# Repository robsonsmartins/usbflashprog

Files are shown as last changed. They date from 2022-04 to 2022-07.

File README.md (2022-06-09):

# usbflashprogUSB Flash/EPROM Programmer
A memory device programmer (Flash/EPROM/E2PROM) board and software, connected to PC by USB port.

[][tag-url] [][commit-url] [][forks-url] [][stars-url] [][issues-url] [][license-url] [][site-url]

[][build-firmware-url]
[][build-software-url]
[][test-software-url]
[][test-firmware-url]
[][codeql-url]

## Contents

* [About the Project](#about-the-project)
* [Current Status](#current-status)
* [Releases](#releases)
* [Documentation](#documentation)
* [Hardware Design](#hardware-design)
* [Firmware Project](#firmware-project)
* [Software Project](#software-project)
* [Contributing](#contributing)
* [License](#license)
* [Contact](#contact)
* [Reference](#reference)

## About The Project

The purpose of this board is to allow the programming, reading and verification of writable/rewritable memory devices, such as EPROM, EEPROM, Flash, SRAM, NVRAM – those with parallel bus as well as serial ones (I2C, SPI, Microwire, LPC).

In a future release, programming of some microcontroller families (eg. Microchip PIC, or 8051) may also be supported, via firmware and software upgrade.

## Current Status

The current status of this project is:










## Releases

The releases of this project are here: [Releases of the USB Flash/EPROM Programmer](https://github.com/robsonsmartins/usbflashprog/releases).

## Documentation

The most up-to-date project documentation can be accessed here: [Documentation of the USB Flash/EPROM Programmer](https://robsonsmartins.github.io/usbflashprog/).

## Hardware Design

The most up-to-date hardware design can be accessed here: [Hardware design of the USB Flash/EPROM Programmer](https://github.com/robsonsmartins/usbflashprog/blob/main/hardware/).

## Firmware Project

The most up-to-date firmware project can be accessed here: [Firmware Project of the USB Flash/EPROM Programmer](https://github.com/robsonsmartins/usbflashprog/blob/main/firmware/).

Instructions on how to build the firmware are described in following document: [Firmware Build Instructions](https://github.com/robsonsmartins/usbflashprog/blob/main/firmware/BUILD.md).

## Software Project

The most up-to-date software project can be accessed here: [Software Project of the USB Flash/EPROM Programmer](https://github.com/robsonsmartins/usbflashprog/blob/main/software/).

Instructions on how to build the software are described in following document: [Software Build Instructions](https://github.com/robsonsmartins/usbflashprog/blob/main/software/BUILD.md).

## Contributing

Please read [CONTRIBUTING](https://github.com/robsonsmartins/usbflashprog/blob/main/CONTRIBUTING.md) for more information.

## License

Distributed under the [Creative Commons Attribution-NonCommercial-ShareAlike 4.0 International License][cc-by-nc-sa]. 

See [LICENSE](https://github.com/robsonsmartins/usbflashprog/blob/main/LICENSE) file for more information.

The same "Terms and Conditions" and "Privacy Policy" of the [Robson Martins Home Page](https://www.robsonmartins.com) apply here:

- [Terms and Conditions](https://www.robsonmartins.com/content/policy/terms.php)
- [Privacy Policy](https://www.robsonmartins.com/content/policy/privacy.php)

## Contact

[][contact-site-url] [][contact-linkedin-url]

## Reference
* [EzoFlash+](http://www.ezoflash.com/) - Parallel Port EPROM/Flash Programmer.
* [MPSP](https://mpsp.robsonmartins.com) - Microchip&copy; PIC Serial Port Programmer.
* [PK2C](https://pk2c.robsonmartins.com) - Microchip&copy; PIC Kit 2 Clone Programmer.

---

This work is licensed under a [Creative Commons Attribution-NonCommercial-ShareAlike 4.0 International License][cc-by-nc-sa].

[][cc-by-nc-sa]

[cc-by-nc-sa]: http://creativecommons.org/licenses/by-nc-sa/4.0/
[cc-by-nc-sa-image]: https://licensebuttons.net/l/by-nc-sa/4.0/88x31.png

[tag-shield]: https://img.shields.io/github/v/tag/robsonsmartins/usbflashprog?style=plastic
[tag-url]: https://github.com/robsonsmartins/usbflashprog/tags
[commit-shield]: https://img.shields.io/github/last-commit/robsonsmartins/usbflashprog?style=plastic
[commit-url]: https://github.com/robsonsmartins/usbflashprog/graphs/commit-activity
[forks-shield]: https://img.shields.io/github/forks/robsonsmartins/usbflashprog?style=plastic
[forks-url]: https://github.com/robsonsmartins/usbflashprog/network/members
[stars-shield]: https://img.shields.io/github/stars/robsonsmartins/usbflashprog?style=plastic
[stars-url]: https://github.com/robsonsmartins/usbflashprog/stargazers
[issues-shield]: https://img.shields.io/github/issues/robsonsmartins/usbflashprog?style=plastic
[issues-url]: https://github.com/robsonsmartins/usbflashprog/issues
[license-shield]: https://img.shields.io/badge/License-CC%20BY--NC--SA%204.0-lightgrey.svg?style=plastic
[license-url]: https://github.com/robsonsmartins/usbflashprog/blob/master/LICENSE
[site-shield]: https://img.shields.io/badge/project%20site-usbflashprog-orange?style=plastic
[site-url]: https://usbflashprog.robsonmartins.com

[build-firmware-shield]: https://github.com/robsonsmartins/usbflashprog/actions/workflows/firmware.yml/badge.svg?style=plastic
[build-firmware-url]: https://github.com/robsonsmartins/usbflashprog/actions/workflows/firmware.yml
[build-software-shield]: https://github.com/robsonsmartins/usbflashprog/actions/workflows/software.yml/badge.svg?style=plastic
[build-software-url]: https://github.com/robsonsmartins/usbflashprog/actions/workflows/software.yml
[test-firmware-shield]: https://github.com/robsonsmartins/usbflashprog/actions/workflows/test-firmware.yml/badge.svg?style=plastic
[test-firmware-url]: https://github.com/robsonsmartins/usbflashprog/actions/workflows/test-firmware.yml
[test-software-shield]: https://github.com/robsonsmartins/usbflashprog/actions/workflows/test-software.yml/badge.svg?style=plastic
[test-software-url]: https://github.com/robsonsmartins/usbflashprog/actions/workflows/test-software.yml
[codeql-shield]: https://github.com/robsonsmartins/usbflashprog/actions/workflows/codeql-analysis.yml/badge.svg?style=plastic
[codeql-url]:https://github.com/robsonsmartins/usbflashprog/actions/workflows/codeql-analysis.yml

[contact-site-shield]: https://img.shields.io/badge/Home%20Page-robsonmartins.com-green?style=plastic
[contact-site-url]: https://www.robsonmartins.com
[contact-linkedin-shield]: https://img.shields.io/badge/LinkedIn-robsonmartins-blue?style=plastic
[contact-linkedin-url]: https://www.linkedin.com/in/robsonmartins/

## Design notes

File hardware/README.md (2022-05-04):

# usbflashprogUSB Flash/EPROM Programmer

A memory device programmer (Flash/EPROM/E2PROM) board and software, connected to PC by USB port.

## Hardware Design

### Schematic Diagram

The most up-to-date schematic diagram can be accessed here: [Schematic diagram of the USB Flash/EPROM Programmer](https://robsonsmartins.github.io/usbflashprog/hardware/usbflashprog_sch.pdf).

### Bill of Materials (BOM)

The most up-to-date BOM can be accessed here: [Bill of Materials of the USB Flash/EPROM Programmer](https://robsonsmartins.github.io/usbflashprog/hardware/usbflashprog_bom.pdf).

## Software versions

The following CAD software (opensource and multiplatform) was used to draw the schematic diagram and PCB:

- [Kicad](https://www.kicad.org), version 6.0.4.

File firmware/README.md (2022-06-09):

# usbflashprogUSB Flash/EPROM Programmer

A memory device programmer (Flash/EPROM/E2PROM) board and software, connected to PC by USB port.

## Firmware Project

### Build Instructions

Instructions on how to build the project are described in following document: [Build Instructions](BUILD.md)

### Raspberry Pi Pico Platform

- [Raspberry Pi Documentation](https://www.raspberrypi.com/documentation/microcontrollers/raspberry-pi-pico.html)
- [Raspberry Pi Pico Datasheet](https://datasheets.raspberrypi.com/pico/pico-datasheet.pdf)
- [Getting started with Raspberry Pi Pico (C/C++)](https://datasheets.raspberrypi.com/pico/getting-started-with-pico.pdf)
- [Raspberry Pi Pico C/C++ SDK](https://www.raspberrypi.com/documentation/microcontrollers/c_sdk.html)

### Code Style Guide

- [Google C++ Style Guide](https://google.github.io/styleguide/cppguide.html)

## Software versions

The following software was used to develop the firmware:

- [Ubuntu GNU/Linux](https://releases.ubuntu.com/jammy/), version 22.04 LTS.
- [Visual Studio Code](https://code.visualstudio.com/), version 1.66.2.
- [OpenOCD](https://github.com/raspberrypi/openocd), version 0.11.0-g610f137.
- [Pico SDK](https://github.com/raspberrypi/pico-sdk), version 1.3.0.
- [ARM GCC](https://packages.ubuntu.com/jammy/gcc-arm-none-eabi), version 15:10.3-2021.07-4.
- [GCC](https://packages.ubuntu.com/jammy/gcc), version 4:11.2.0-1ubuntu1.
- [CMake](https://packages.ubuntu.com/jammy/cmake), version 3.22.1-1ubuntu1.
- [Google Test](https://packages.ubuntu.com/jammy/googletest), version 1.11.0-3.
- [Doxygen](https://packages.ubuntu.com/jammy/doxygen), version 1.9.1-2ubuntu2.

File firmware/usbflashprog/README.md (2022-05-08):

## USB EPROM/Flash Programmer

A memory device programmer (Flash/EPROM/E2PROM) board and software, connected to PC by USB port.

### About The Project

The purpose of this board is to allow the programming, reading and verification of writable/rewritable memory devices, such as EPROM, EEPROM, Flash, SRAM, NVRAM – those with parallel bus as well as serial ones (I2C, SPI, Microwire, LPC).

In a future release, programming of some microcontroller families (eg. Microchip PIC, or 8051) may also be supported, via firmware and software upgrade.

### License

This work is licensed under a [Creative Commons Attribution-NonCommercial-ShareAlike 4.0 International License](http://creativecommons.org/licenses/by-nc-sa/4.0/).



### Repository

- [Firmware Project](https://github.com/robsonsmartins/usbflashprog/tree/main/firmware)

### Firmware Documentation

The most up-to-date firmware documentation can be accessed here: [Firmware Documentation of the USB Flash/EPROM Programmer](https://robsonsmartins.github.io/usbflashprog/firmware/html/index.html).

### Code Coverage Report

The code coverage report from unit tests can be accessed here: [Code Coverage Report of the USB Flash/EPROM Programmer](https://robsonsmartins.github.io/usbflashprog/firmware/lcov/index.html).

### Raspberry Pi Pico Platform

- [Raspberry Pi Documentation](https://www.raspberrypi.com/documentation/microcontrollers/raspberry-pi-pico.html)
- [Raspberry Pi Pico Datasheet](https://datasheets.raspberrypi.com/pico/pico-datasheet.pdf)
- [Getting started with Raspberry Pi Pico (C/C++)](https://datasheets.raspberrypi.com/pico/getting-started-with-pico.pdf)
- [Raspberry Pi Pico C/C++ SDK](https://www.raspberrypi.com/documentation/microcontrollers/c_sdk.html)

### Code Style Guide

- [Google C++ Style Guide](https://google.github.io/styleguide/cppguide.html)

### Software versions

The following software was used to develop the firmware:

- [Ubuntu GNU/Linux](https://releases.ubuntu.com/jammy/), version 22.04 LTS.
- [Visual Studio Code](https://code.visualstudio.com/), version 1.66.2.
- [OpenOCD](https://github.com/raspberrypi/openocd), version 0.11.0-g610f137.
- [Pico SDK](https://github.com/raspberrypi/pico-sdk), version 1.3.0.
- [ARM GCC](https://packages.ubuntu.com/jammy/gcc-arm-none-eabi), version 15:10.3-2021.07-4.
- [GCC](https://packages.ubuntu.com/jammy/gcc), version 4:11.2.0-1ubuntu1.
- [CMake](https://packages.ubuntu.com/jammy/cmake), version 3.22.1-1ubuntu1.
- [Google Test](https://packages.ubuntu.com/jammy/googletest), version 1.11.0-3.
- [LCov](https://packages.ubuntu.com/jammy/lcov), version 1.15-1.
- [Doxygen](https://packages.ubuntu.com/jammy/doxygen), version 1.9.1-2ubuntu2.

**author** [Robson Martins](https://www.robsonmartins.com)

**version** 0.1

**date** 2022

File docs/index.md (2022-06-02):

# usbflashprogUSB Flash/EPROM Programmer

A memory device programmer (Flash/EPROM/E2PROM) board and software, connected to PC by USB port.

## Project Site

[USB Flash/EPROM Programmer Project Site](https://usbflashprog.robsonmartins.com)

## Documentation

### Specifications

The most up-to-date project specifications can be accessed here: [Specifications of the USB Flash/EPROM Programmer](https://robsonsmartins.github.io/usbflashprog/specs.pdf).

### Firmware Documentation

The most up-to-date firmware documentation can be accessed here: [Firmware Documentation of the USB Flash/EPROM Programmer](https://robsonsmartins.github.io/usbflashprog/firmware/html/index.html).

### Software Documentation

The most up-to-date software documentation can be accessed here: [Software Documentation of the USB Flash/EPROM Programmer](https://robsonsmartins.github.io/usbflashprog/software/html/index.html).

### Hardware Documentation

#### Schematic Diagram

The most up-to-date schematic diagram can be accessed here: [Schematic diagram of the USB Flash/EPROM Programmer](https://robsonsmartins.github.io/usbflashprog/hardware/usbflashprog_sch.pdf).

#### Bill of Materials (BOM)

The most up-to-date BOM can be accessed here: [Bill of Materials of the USB Flash/EPROM Programmer](https://robsonsmartins.github.io/usbflashprog/hardware/usbflashprog_bom.pdf).

## Software versions

The following software (open source/freeware and multiplatform) were used to write the documentation:

- [LibreOffice](https://www.libreoffice.org/), version 7.3.2.2.
- [yEd Graph Editor](https://www.yworks.com/products/yed), version 3.22.
- [Doxygen](https://packages.ubuntu.com/jammy/doxygen), version 1.9.1-2ubuntu2.

---

This work is licensed under a [Creative Commons Attribution-NonCommercial-ShareAlike 4.0 International License][cc-by-nc-sa].

[][cc-by-nc-sa]

[cc-by-nc-sa]: http://creativecommons.org/licenses/by-nc-sa/4.0/
[cc-by-nc-sa-image]: https://licensebuttons.net/l/by-nc-sa/4.0/88x31.png

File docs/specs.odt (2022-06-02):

USB Flash / EPROM Programmer

https://usbflashprog.robsonmartins.com

Specifications

Version 0.1 - Revision F

Author: Robson Martins (https://www.robsonmartins.com)

History

Revision | Date | Changes
F | May. 30, 2022 | Added serial communication protocol (opcodes).
E | Apr. 23, 2022 | CPU changed to Raspberry Pi Pico. Updated diagrams. Removed PT_BR translation.
D | Feb. 02, 2011 | Added firmware project.
C | Dec. 27, 2010 | Added adapter connectors pin-out.
B | Mar. 03, 2010 | New Block Diagram.
A | Jan. 28, 2010 | Initial Version.

# Introduction

The purpose of this board is to allow the programming, reading and verification of writable/rewritable memory devices, such as EPROM, EEPROM, Flash, SRAM, NVRAM – those with parallel bus as well as serial ones (I2C, SPI, Microwire, LPC).

In a future release, programming of some microcontroller families (eg. Microchip PIC, or 8051) may also be supported, via firmware and software upgrade.

# Requirements

- Allow write, read, delete, get ID and information about supported chips.
- Support parallel and serial devices (no microcontrollers in initial version).
- Support SRAM, EPROM, E2PROM, Flash, NVRAM, Hub/LPC devices (parallel and serial, including Microwire, I2C, SPI).
- Provide two sources of programming voltage: VDD (low voltage) and VPP/VEE (high voltage for write/erase), in the range between 3.3 V and 6.8 V (VDD), and between 12V and 25V (VPP/VEE).
- Automatic control for VDD and VPP/VEE voltages, according to the chip to be programmed.
- Allow jumperless chip configuration (by software chip selection).
- Socket for adapters – for each package or family of supported chips (no ZIF socket on the programmer board).
- Algorithms for chip read/write operations must be loaded on the main board of the programmer through ‘scripts’, avoiding the use of processing by software running on the PC.
- Connection with PC via USB port, using a specific software for communication.
- Multi-platform software, compatible with Microsoft Windows® or GNU/Linux® operating systems, under 32 or 64 bits (if possible, Apple MacOSX® and FreeBSD versions can be available).
- Some compatibility with existing programmers adapters:
  - EzoFlash+ (http://www.ezoflash.com/).
  - MPSP (https://mpsp.robsonmartins.com).

# Hardware Platform

## Block Diagram

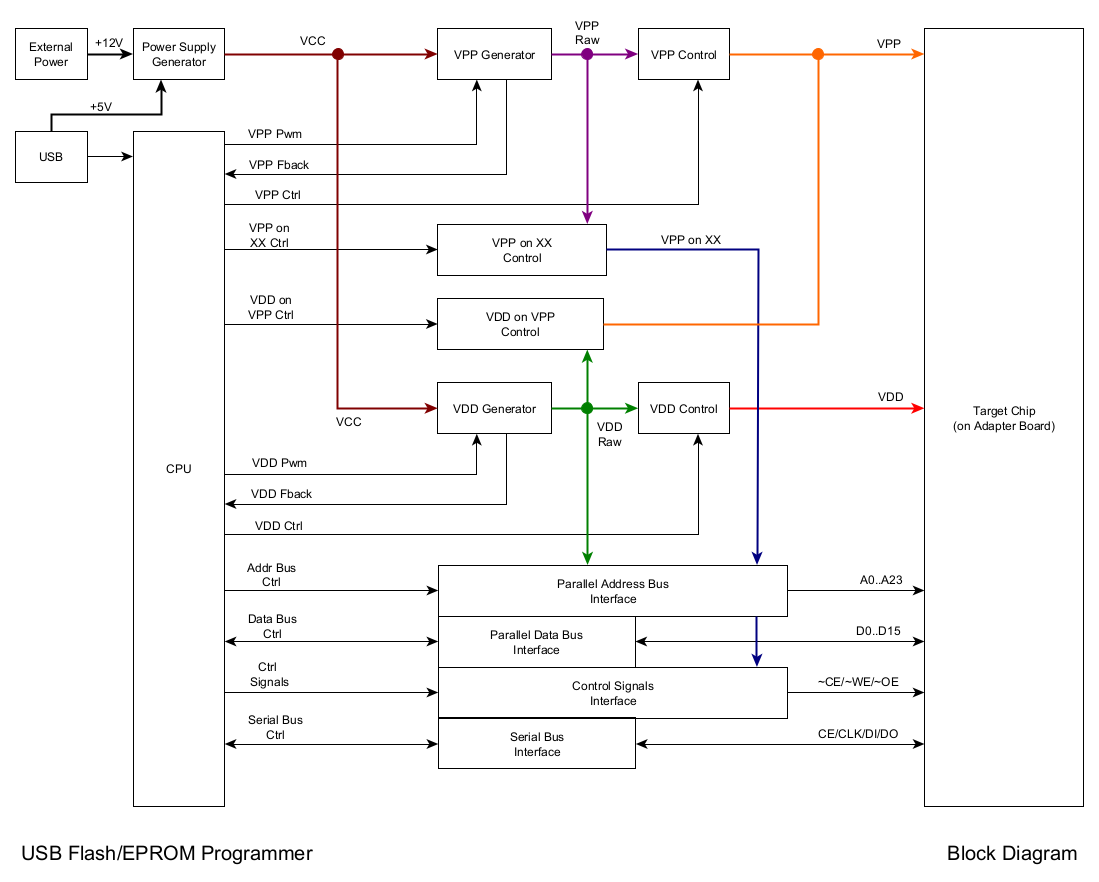
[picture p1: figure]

## Functional Description

### Main CPU

The CPU used in this programmer will be a Raspberry Pi Pico Module (with a RP2040 processor and USB support). This module has a dual core ARM Cortex-M0+ running at 133MHz, 256KB of SRAM and 2MB of storage, a USB port, required for communication between the programmer and the PC, plus one A/D converter with 3 inputs and 16 PWM channels (that can be used to generate the programming voltages). Moreover, there is a serial communication port (SPI / Microwire / I2C) that can be used for programming of serial devices, and GPIO pins to control parallel bus and signals.

### Power Supplies

To generate the programming voltages (VDD and VPP/VEE), the programmer must have two DC/DC converters, driven by the PWM outputs of the CPU and monitored through of the ADC inputs.

Both the CPU and the two DC/DC converters will be powered by voltage supplied by USB port (5V), and/or by external power supply connector.

The CPU can turn on or off the VDD / VPP / VEE outputs, or supply VDD voltage on VPP line (via the “VDD on VPP” signal).

### Programmer Busses

For handle parallel devices, the programmer must provide the following busses and signals to the target chip:

- Address Bus (A0..A23) – A addressing bus with 24 bits wide, allowing access up to 16777216 positions (16M).
- Data Bus (D0..D7 / D8..D15) – A data bus with 8 or 16 bits wide, allowing access for one byte (8 bits) or one word (16 bits), according to the memory width.
- Control Lines (~CE / ~WE / ~OE) – Chip Enable, Write Enable e Output Enable.
- Power and Programming Voltages (VDD / VPP / VEE) - Voltages used to power-up (VDD), program (VPP) or erase (VEE) the memory.

For handle serial devices, the programmer must provide the following signals to the target chip:

- Clock (CLK) – Clock line for synchronize the communication with the target memory.
- Data Input (DIN) – For read data from target memory.
- Data Output (DOUT) – For write data to target memory.
- Control Lines (~CE / ~WE / ~OE) – Chip Enable, Write Enable e Output Enable.
- Power and Programming Voltages (VDD / VPP / VEE) - Voltages used to power-up (VDD), program (VPP) or erase (VEE) the memory.

### Busses Interfaces

To connect the microcontroller busses to target chip, is necessary adapt the voltage levels of the CPU (5V) and the voltage levels of the target chip (3.3V <= VDD <= 6.8V), using an interface circuitry.

## Adapter Connector Pin-Out

### Parallel Adapter Connector

Female (Top Side)

1 | 3 | 5 | 7 | 9 | 11 | 13 | 15 | 17 | 19 | 21 | 23 | 25 | 27 | 29 | 31 | 33 | 35 | 37 | 39 | 41 | 43 | 45 | 47
2 | 4 | 6 | 8 | 10 | 12 | 14 | 16 | 18 | 20 | 22 | 24 | 26 | 28 | 30 | 32 | 34 | 36 | 38 | 40 | 42 | 44 | 46 | 48

Pin | Function | Description
1 | D0 | DATA BUS – BIT 0
2 | D1 | DATA BUS – BIT 1
3 | D2 | DATA BUS – BIT 2
4 | GND | GROUND
5 | D3 | DATA BUS – BIT 3
6 | D4 | DATA BUS – BIT 4
7 | D5 | DATA BUS – BIT 5
8 | D6 | DATA BUS – BIT 6
9 | D7 | DATA BUS – BIT 7
10 | CE | CHIP ENABLE
11 | A10 | ADDRESS BUS – BIT 10
12 | OE | OUTPUT ENABLE
13 | A11 | ADDRESS BUS – BIT 11
14 | A9 | ADDRESS BUS – BIT 9
15 | A8 | ADDRESS BUS – BIT 8
16 | A13 | ADDRESS BUS – BIT 13
17 | A14 | ADDRESS BUS – BIT 14
18 | A17 | ADDRESS BUS – BIT 17
19 | WE | WRITE ENABLE
20 | VDD | VDD VOLTAGE
21 | A18 | ADDRESS BUS – BIT 18
22 | A16 | ADDRESS BUS – BIT 16
23 | A15 | ADDRESS BUS – BIT 15
24 | A12 | ADDRESS BUS – BIT 12
25 | A7 | ADDRESS BUS – BIT 7
26 | A6 | ADDRESS BUS – BIT 6
27 | A5 | ADDRESS BUS – BIT 5
28 | A4 | ADDRESS BUS – BIT 4
29 | A3 | ADDRESS BUS – BIT 3
30 | A2 | ADDRESS BUS – BIT 2
31 | A1 | ADDRESS BUS – BIT 1
32 | A0 | ADDRESS BUS – BIT 0
33 | KEY | KEY TO AVOID CONNECTOR INVERSION
34 | VPP | VPP PROGRAMMING VOLTAGE
35 | A19 | ADDRESS BUS – BIT 19
36 | A20 | ADDRESS BUS – BIT 20
37 | A21 | ADDRESS BUS – BIT 21
38 | A22 | ADDRESS BUS – BIT 22
39 | A23 | ADDRESS BUS – BIT 23
40 | KEY | KEY TO AVOID CONNECTOR INVERSION
41 | D8 | DATA BUS – BIT 8
42 | D9 | DATA BUS – BIT 9
43 | D10 | DATA BUS – BIT 10
44 | D11 | DATA BUS – BIT 11
45 | D12 | DATA BUS – BIT 12
46 | D13 | DATA BUS – BIT 13
47 | D14 | DATA BUS – BIT 14
48 | D15 | DATA BUS – BIT 15

### Serial Adapter Connector

Female (Top Side)

1 | 3 | 5 | 7 | 9 | 11 | 13 | 15 | 17 | 19
2 | 4 | 6 | 8 | 10 | 12 | 14 | 16 | 18 | 20

Pin | Function | Description
1 | VPP13 | VPP PROGRAMMING VOLTAGE (13V)
2 | VPP13 | VPP PROGRAMMING VOLTAGE (13V)
3 | VDD5 | VDD VOLTAGE (5V)
4 | VDD5 | VDD VOLTAGE (5V)
5 | GND | GROUND
6 | GND | GROUND
7 | SCK | SERIAL CLOCK
8 | SCK | SERIAL CLOCK
9 | GND | GROUND
10 | GND | GROUND
11 | SDO | SERIAL DATA OUT (TO TARGET SDI)
12 | SDI | SERIAL DATA IN (FROM TARGET SDO)
13 | GND | GROUND
14 | GND | GROUND
15 | VCC | VCC SUPPLY (5V – ALWAYS ON)
16 | VCC | VCC SUPPLY (5V – ALWAYS ON)
17 | WE | CHIP SELECT (WE PROGRAMMER PIN)
18 | WE | CHIP SELECT (WE PROGRAMMER PIN)
19 | GND | GROUND
20 | KEY | KEY TO AVOID CONNECTOR INVERSION

# Firmware Project

## Block Diagram

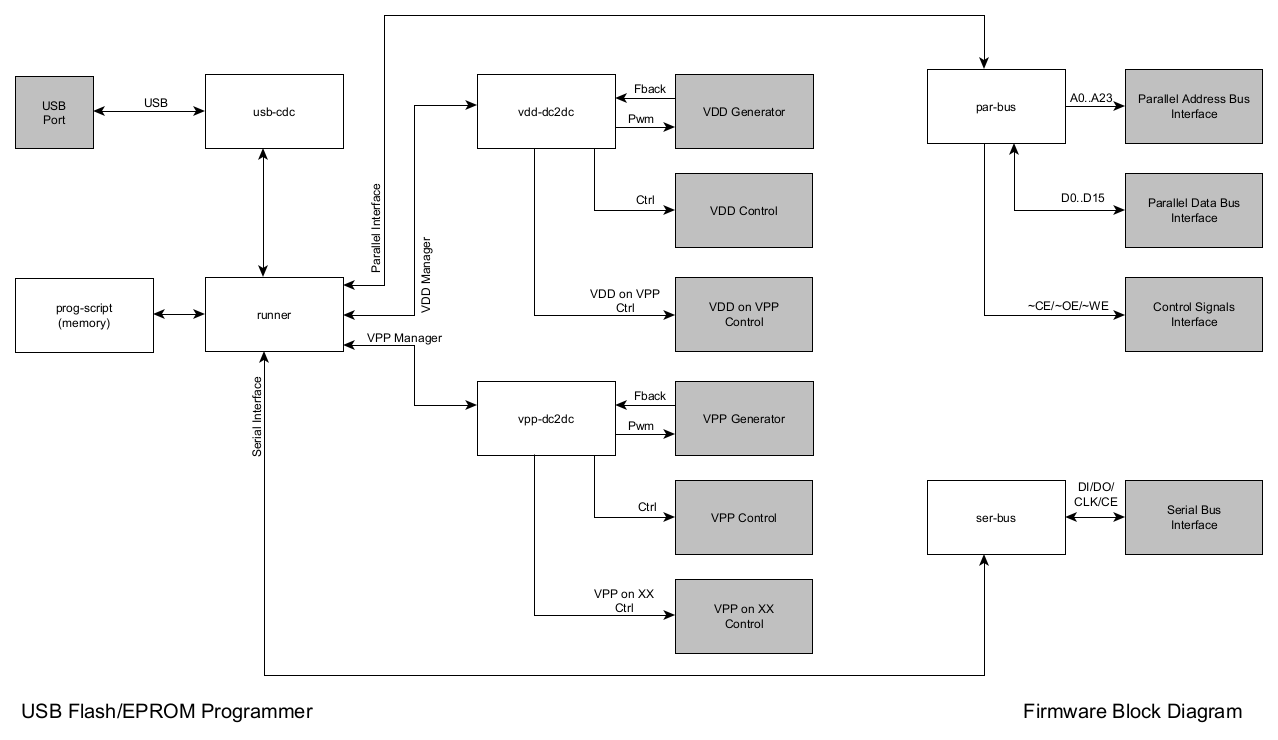
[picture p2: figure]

## Communication Protocol (Opcodes)

For communication between the programmer’s hardware and the PC, the following protocol must be used (via USB-CDC serial class).

### Response Codes

Op Code | Mnemonic | Description
0x00 | CMD RESPONSE NOK | Response NOK.
0x01 | CMD RESPONSE OK | Response OK.

### Command Codes

Op Code | Mnemonic | Parameters | Response | Description
0x00 | NOP | <none> | OK | No Operation.
0x01 | CMD VDD CTRL | STATE | OK NOK | Set VDD Ctrl Pin On or Off. Parameter STATE is one byte size. If STATE == 0x00, will be OFF; If STATE != 0x00, will be ON.
0x02 | CMD VDD SETV | VALUE | OK NOK | Set VDD Voltage. Parameter VALUE is two byte size. FIRST = Integer part of value SECOND = Fractional part of value
0x03 | CMD VDD GETV | <none> | OK + VALUE NOK | Get VDD Voltage. Response VALUE is two byte size. FIRST = Integer part of value SECOND = Fractional part of value
0x04 | CMD VDD GET% | <none> | OK + VALUE NOK | Get VDD PWM Duty Cycle (%). Response VALUE is two byte size. FIRST = Integer part of value SECOND = Fractional part of value
0x05 | CMD VDD GETCAL | <none> | OK + VALUE NOK | Get VDD Calibration Value. Response VALUE is two byte size. FIRST = Integer part of value SECOND = Fractional part of value
0x06 | CMD VDD INITCAL | <none> | OK NOK | Init VDD Calibration Process.
0x07 | CMD VDD SAVECAL | VALUE | OK NOK | Save VDD Calibration Value. Parameter VALUE is two byte size. FIRST = Integer part of value SECOND = Fractional part of value
0x08 | CMD VDD ON VPP | STATE | OK NOK | Set VDD On VPP Pin On or Off. Parameter STATE is one byte size. If STATE == 0x00, will be OFF; If STATE != 0x00, will be ON.
0x11 | CMD VPP CTRL | STATE | OK NOK | Set VPP Ctrl Pin On or Off. Parameter STATE is one byte size. If STATE == 0x00, will be OFF; If STATE != 0x00, will be ON.
0x12 | CMD VPP SETV | VALUE | OK NOK | Set VPP Voltage. Parameter VALUE is two byte size. FIRST = Integer part of value SECOND = Fractional part of value
0x13 | CMD VPP GETV | <none> | OK + VALUE NOK | Get VPP Voltage. Response VALUE is two byte size. FIRST = Integer part of value SECOND = Fractional part of value
0x14 | CMD VPP GET% | <none> | OK + VALUE NOK | Get VPP PWM Duty Cycle (%). Response VALUE is two byte size. FIRST = Integer part of value SECOND = Fractional part of value
0x15 | CMD VPP GETCAL | <none> | OK + VALUE NOK | Get VPP Calibration Value. Response VALUE is two byte size. FIRST = Integer part of value SECOND = Fractional part of value
0x16 | CMD VPP INITCAL | <none> | OK NOK | Init VPP Calibration Process.
0x17 | CMD VPP SAVECAL | VALUE | OK NOK | Save VPP Calibration Value. Parameter VALUE is two byte size. FIRST = Integer part of value SECOND = Fractional part of value
0x18 | CMD VPP ON A9 | STATE | OK NOK | Set VPP On A9 Pin On or Off. Parameter STATE is one byte size. If STATE == 0x00, will be OFF; If STATE != 0x00, will be ON.
0x19 | CMD VPP ON A18 | STATE | OK NOK | Set VPP On A18 Pin On or Off. Parameter STATE is one byte size. If STATE == 0x00, will be OFF; If STATE != 0x00, will be ON.
0x1A | CMD VPP ON CE | STATE | OK NOK | Set VPP On CE Pin On or Off. Parameter STATE is one byte size. If STATE == 0x00, will be OFF; If STATE != 0x00, will be ON.
0x1B | CMD VPP ON OE | STATE | OK NOK | Set VPP On OE Pin On or Off. Parameter STATE is one byte size. If STATE == 0x00, will be OFF; If STATE != 0x00, will be ON.
0x1C | CMD VPP ON WE | STATE | OK NOK | Set VPP On WE Pin On or Off. Parameter STATE is one byte size. If STATE == 0x00, will be OFF; If STATE != 0x00, will be ON.
0x21 | CMD BUS CE CTRL | STATE | OK NOK | Set CE Pin On or Off. Parameter STATE is one byte size. If STATE == 0x00, will be OFF; If STATE != 0x00, will be ON.
0x22 | CMD BUS OE CTRL | STATE | OK NOK | Set OE Pin On or Off. Parameter STATE is one byte size. If STATE == 0x00, will be OFF; If STATE != 0x00, will be ON.
0x23 | CMD BUS WE CTRL | STATE | OK NOK | Set WE Pin On or Off. Parameter STATE is one byte size. If STATE == 0x00, will be OFF; If STATE != 0x00, will be ON.
0x31 | CMD BUS AD CLR | <none> | OK NOK | Clear Address Bus Value (Set Address to 0x00).
0x32 | CMD BUS AD INC | <none> | OK NOK | Increment Address Bus Value.
0x33 | CMD BUS AD SET | VALUE | OK NOK | Set Address Bus Value. Parameter VALUE is three byte size. FIRST = HI SECOND = MID THIRD = LOW
0x34 | CMD BUS AD SETB | VALUE | OK NOK | Set Address Bus Value (BYTE). Parameter VALUE is one byte size. VALUE = LOW
0x35 | CMD BUS AD SETW | VALUE | OK NOK | Set Address Bus Value (WORD). Parameter VALUE is two byte size. FIRST = MID SECOND = LOW
0x41 | CMD BUS DT CLR | <none> | OK NOK | Clear Data Bus Value (Set Data to 0x00).
0x42 | CMD BUS DT SET | VALUE | OK NOK | Set Data Bus Value. Parameter VALUE is two byte size. FIRST = HI SECOND = LOW
0x43 | CMD BUS DT SETB | VALUE | OK NOK | Set Data Bus Value (BYTE). Parameter VALUE is one byte size. VALUE = LOW
0x44 | CMD BUS DT GET | <none> | OK + VALUE NOK | Get Data Bus Value. Response VALUE is two byte size. FIRST = HI SECOND = LOW
0x45 | CMD BUS DT GETB | <none> | OK + VALUE NOK | Get Data Bus Value (BYTE). Response VALUE is one byte size. VALUE = LOW
TODO | CMD SERIAL BUS | | | TODO: Serial Bus Commands.

Appendix A – Development Environment

To develop the programmer, should be used only open source and freeware software:

- Operating System:
  - GNU/Linux (https://distrowatch.com/)
- Documentation:
  - LibreOffice (https://www.libreoffice.org/)
  - yEd Graph Editor (https://www.yworks.com/products/yed)
- Hardware Development:
  - CAD:
    - Kicad (https://www.kicad.org)
- Firmware Development:
  - Raspberry Pi Pico Module:
    - Raspberry Pi Pico (https://www.raspberrypi.com/products/raspberry-pi-pico/)
- Software Development:
  - C/C++ Compiler:
    - GCC (https://gcc.gnu.org/)
  - GUI Framework:
    - Qt (https://www.qt.io)
  - IDE:
    - Qt Creator (https://www.qt.io/product/development-tools)
    - Microsoft Visual Studio Code (https://code.visualstudio.com/)
  - Code Documentation:
    - Doxygen (https://www.doxygen.org/)
  - Software Modeling:
    - Umbrello (https://umbrello.kde.org/)
- Version Control System:
  - Git (https://git-scm.com/)

USB Flash / EPROM Programmer 3

USB Flash / EPROM Programmer 5

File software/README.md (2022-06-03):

# usbflashprogUSB Flash/EPROM Programmer

A memory device programmer (Flash/EPROM/E2PROM) board and software, connected to PC by USB port.

## Software Project

### Build Instructions

Instructions on how to build the project are described in following document: [Build Instructions](BUILD.md)

### Code Style Guide

- [Google C++ Style Guide](https://google.github.io/styleguide/cppguide.html)

## Software versions

The following software was used to develop the software:

- [Ubuntu GNU/Linux](https://releases.ubuntu.com/jammy/), version 22.04 LTS.
- [Visual Studio Code](https://code.visualstudio.com/), version 1.66.2.
- [GCC](https://packages.ubuntu.com/jammy/gcc), version 4:11.2.0-1ubuntu1.
- [Qt](https://packages.ubuntu.com/jammy/qttools5-dev-tools), version 5.15.3-1.
- [Qt tools support for VSCode](https://marketplace.visualstudio.com/items?itemName=tonka3000.qtvsctools), version 0.11.0.
- [CMake](https://packages.ubuntu.com/jammy/cmake), version 3.22.1-1ubuntu1.
- [Google Test](https://packages.ubuntu.com/jammy/googletest), version 1.11.0-3.
- [Doxygen](https://packages.ubuntu.com/jammy/doxygen), version 1.9.1-2ubuntu2.

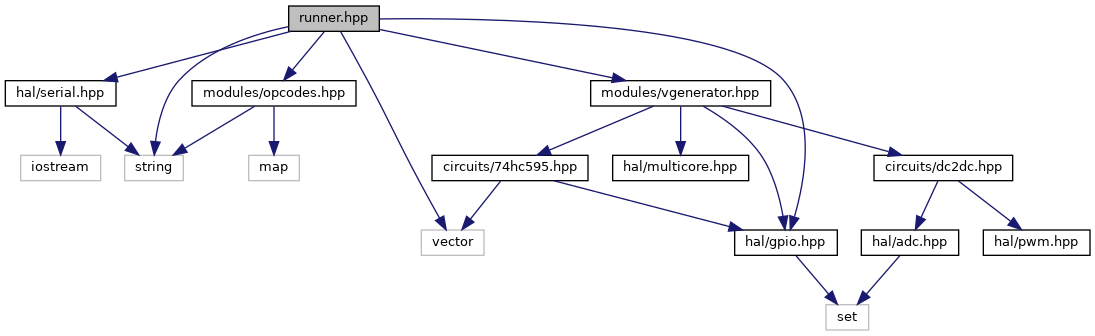
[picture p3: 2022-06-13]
docs/firmware/html/a00072.png

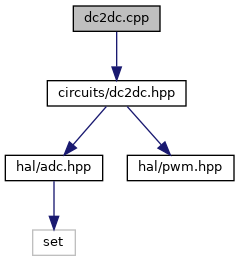
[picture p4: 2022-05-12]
docs/firmware/html/a00009.png

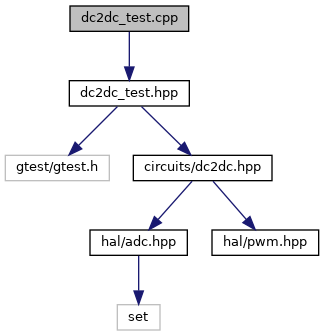
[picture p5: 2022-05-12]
docs/firmware/html/a00090.png

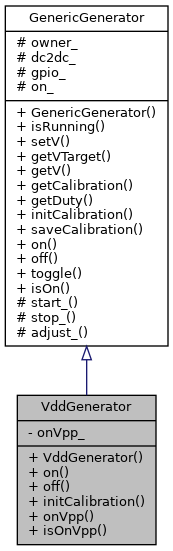
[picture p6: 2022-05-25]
docs/firmware/html/a01061.png

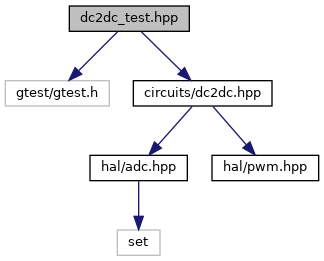
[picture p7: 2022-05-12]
docs/firmware/html/a00093.png

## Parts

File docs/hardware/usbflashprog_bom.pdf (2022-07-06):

## USB Flash / EPROM Programmer

## BOM (Bill of Materials)

Source: | usbflashprog.kicad_sch
Date: | 06/07/22 00:07
Tool: | Eeschema (6.0.4)
Generator: | bom_csv_grouped_by_value.py
Component Count: 123
Item | Qty | Reference(s) | Value
1 | 1 | C1 | 10uF x 25V
2 | 1 | C2 | 10uF x 16V
3 | 13 | C3, C5, C7, C9, C10, C11, C12, C13, C14, C15, C16, C17, C18 | 100nF
4 | 1 | C4 | 470uF x 16V
5 | 1 | C6 | 22uF x 16V
6 | 1 | C8 | 100uF x 50V
7 | 3 | D1, D2, D4 | 1N4001
8 | 1 | D3 | LED GREEN 3mm
9 | 3 | D5, D7, D11 | BAT46
10 | 1 | D6 | LED RED 3mm
11 | 2 | D8, D19 | 1N4733A (5V1)
12 | 8 | D9, D12, D13, D14, D15, D16, D17, D18 | 1N4148
13 | 1 | D10 | LED YELLOW 3mm
14 | 1 | D20 | 1N4743A (13V)
15 | 1 | J1 | Power Jack
16 | 1 | J2 | 48 pin socket
17 | 1 | J3 | 20 pin socket
18 | 1 | L1 | 100uH
19 | 1 | L2 | 300uH
20 | 6 | Q1, Q12, Q13, Q14, Q15, Q16 | BC547
21 | 4 | Q2, Q3, Q4, Q6 | BC327
22 | 1 | Q5 | TIP120
23 | 5 | Q7, Q8, Q9, Q10, Q11 | BC557
24 | 14 | R1, R5, R6, R7, R12, R13, R18, R25, R26, R33, R35, R37, R49, R50 | 2K2 x 1/8W
25 | 5 | R27, R28, R38, R39, R42 | 2K2 x 1W
26 | 3 | R2, R15, R40 | 100R x 1/8W
27 | 2 | R11, R51 | 100R x 1/2W
28 | 7 | R3, R8, R22, R43, R45, R47, R48 | 1K x 1/8W
29 | 10 | R4, R17, R19, R23, R24, R29, R30, R31, R44, R46 | 4K7 x 1/8W
30 | 5 | R9, R21, R34, R36, R41 | 470R x 1/8W
31 | 1 | R10 | 330R x 1/8W
32 | 2 | R14, R32 | 10K x 1/8W
33 | 1 | R16 | 220R x 1/8W
34 | 1 | R20 | 3K9 x 1/8W
35 | 1 | R52 | 560R x 1W
36 | 1 | U1 | LM7809
37 | 2 | U2, U8 | 74LS06N
38 | 1 | U3 | Raspberry Pi Pico
39 | 6 | U4, U5, U6, U7, U9, U10 | 74HC595
40 | 2 | U11, U12 | 74HC165

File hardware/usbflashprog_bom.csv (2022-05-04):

Source: | usbflashprog.kicad_sch
Date: | 27/04/2022 23:32:14
Tool: | Eeschema (6.0.4)
Generator: | bom_csv_grouped_by_value.py
Component Count: | 123
Individual Components:
Item | Qty | Reference(s) | Value | LibPart | Footprint | Datasheet
 |  | C1 | 10uF | Device:C_Polarized | Capacitor_THT:CP_Radial_D8.0mm_P3.50mm | ~
 |  | C2 | 10uF | Device:C_Polarized | Capacitor_THT:CP_Radial_D8.0mm_P3.50mm | ~
 |  | C3 | 100nF | Device:C | Capacitor_THT:C_Disc_D6.0mm_W2.5mm_P5.00mm | ~
 |  | C4 | 470uF | Device:C_Polarized | Capacitor_THT:CP_Radial_D10.0mm_P7.50mm | ~
 |  | C5 | 100nF | Device:C | Capacitor_THT:C_Disc_D6.0mm_W2.5mm_P5.00mm | ~
 |  | C6 | 22uF | Device:C_Polarized | Capacitor_THT:CP_Radial_D8.0mm_P3.50mm | ~
 |  | C7 | 100nF | Device:C | Capacitor_THT:C_Disc_D6.0mm_W2.5mm_P5.00mm | ~
 |  | C8 | 100uF | Device:C_Polarized | Capacitor_THT:C_Disc_D6.0mm_W2.5mm_P5.00mm | ~
 |  | C9 | 100nF | Device:C | Capacitor_THT:C_Disc_D6.0mm_W2.5mm_P5.00mm | ~
 |  | C10 | 100nF | Device:C | Capacitor_THT:C_Disc_D6.0mm_W2.5mm_P5.00mm | ~
 |  | C11 | 100nF | Device:C | Capacitor_THT:C_Disc_D6.0mm_W2.5mm_P5.00mm | ~
 |  | C12 | 100nF | Device:C | Capacitor_THT:C_Disc_D6.0mm_W2.5mm_P5.00mm | ~
 |  | C13 | 100nF | Device:C | Capacitor_THT:C_Disc_D6.0mm_W2.5mm_P5.00mm | ~
 |  | C14 | 100nF | Device:C | Capacitor_THT:C_Disc_D6.0mm_W2.5mm_P5.00mm | ~
 |  | C15 | 100nF | Device:C | Capacitor_THT:C_Disc_D6.0mm_W2.5mm_P5.00mm | ~
 |  | C16 | 100nF | Device:C | Capacitor_THT:C_Disc_D6.0mm_W2.5mm_P5.00mm | ~
 |  | C17 | 100nF | Device:C | Capacitor_THT:C_Disc_D6.0mm_W2.5mm_P5.00mm | ~
 |  | C18 | 100nF | Device:C | Capacitor_THT:C_Disc_D6.0mm_W2.5mm_P5.00mm | ~
 |  | D1 | 1N4001 | Diode:1N4001 | Diode_THT:D_DO-41_SOD81_P10.16mm_Horizontal | http://www.vishay.com/docs/88503/1n4001.pdf
 |  | D2 | 1N4001 | Diode:1N4001 | Diode_THT:D_DO-41_SOD81_P10.16mm_Horizontal | http://www.vishay.com/docs/88503/1n4001.pdf
 |  | D3 | GREEN | Device:LED | LED_THT:LED_D3.0mm | ~
 |  | D4 | 1N4001 | Diode:1N4001 | Diode_THT:D_DO-41_SOD81_P10.16mm_Horizontal | http://www.vishay.com/docs/88503/1n4001.pdf
 |  | D5 | BAT46 | Diode:BAT46 | Diode_THT:D_DO-35_SOD27_P7.62mm_Horizontal | http://www.vishay.com/docs/85662/bat46.pdf
 |  | D6 | RED | Device:LED | LED_THT:LED_D3.0mm | ~
 |  | D7 | BAT46 | Diode:BAT46 | Diode_THT:D_DO-35_SOD27_P7.62mm_Horizontal | http://www.vishay.com/docs/85662/bat46.pdf
 |  | D8 | 1N4733A | Diode:1N47xxA | Diode_THT:D_DO-41_SOD81_P10.16mm_Horizontal | https://www.vishay.com/docs/85816/1n4728a.pdf
 |  | D9 | 1N4148 | Diode:1N4148 | Diode_THT:D_DO-35_SOD27_P7.62mm_Horizontal | https://assets.nexperia.com/documents/data-sheet/1N4148_1N4448.pdf
 |  | D10 | YELLOW | Device:LED | LED_THT:LED_D3.0mm | ~
 |  | D11 | BAT46 | Diode:BAT46 | Diode_THT:D_DO-35_SOD27_P7.62mm_Horizontal | http://www.vishay.com/docs/85662/bat46.pdf
 |  | D12 | 1N4148 | Diode:1N4148 | Diode_THT:D_DO-35_SOD27_P7.62mm_Horizontal | https://assets.nexperia.com/documents/data-sheet/1N4148_1N4448.pdf
 |  | D13 | 1N4148 | Diode:1N4148 | Diode_THT:D_DO-35_SOD27_P7.62mm_Horizontal | https://assets.nexperia.com/documents/data-sheet/1N4148_1N4448.pdf
 |  | D14 | 1N4148 | Diode:1N4148 | Diode_THT:D_DO-35_SOD27_P7.62mm_Horizontal | https://assets.nexperia.com/documents/data-sheet/1N4148_1N4448.pdf
 |  | D15 | 1N4148 | Diode:1N4148 | Diode_THT:D_DO-35_SOD27_P7.62mm_Horizontal | https://assets.nexperia.com/documents/data-sheet/1N4148_1N4448.pdf
 |  | D16 | 1N4148 | Diode:1N4148 | Diode_THT:D_DO-35_SOD27_P7.62mm_Horizontal | https://assets.nexperia.com/documents/data-sheet/1N4148_1N4448.pdf
 |  | D17 | 1N4148 | Diode:1N4148 | Diode_THT:D_DO-35_SOD27_P7.62mm_Horizontal | https://assets.nexperia.com/documents/data-sheet/1N4148_1N4448.pdf
 |  | D18 | 1N4148 | Diode:1N4148 | Diode_THT:D_DO-35_SOD27_P7.62mm_Horizontal | https://assets.nexperia.com/documents/data-sheet/1N4148_1N4448.pdf
 |  | D19 | 1N4733A | Diode:1N47xxA | Diode_THT:D_DO-41_SOD81_P10.16mm_Horizontal | https://www.vishay.com/docs/85816/1n4728a.pdf
 |  | D20 | 1N4743A | Diode:1N47xxA | Diode_THT:D_DO-41_SOD81_P10.16mm_Horizontal | https://www.vishay.com/docs/85816/1n4728a.pdf
 |  | J1 | 12-18V | Connector:Barrel_Jack_Switch | Connector_BarrelJack:BarrelJack_Horizontal | ~
 |  | J2 | Parallel Adapter | Connector_Generic:Conn_02x24_Odd_Even | Connector_PinSocket_2.54mm:PinSocket_2x24_P2.54mm_Vertical | ~
 |  | J3 | Serial Adapter | Connector_Generic:Conn_02x10_Odd_Even | Connector_PinSocket_2.54mm:PinSocket_2x10_P2.54mm_Vertical | ~
 |  | L1 | 100uH | Device:L_Ferrite | Inductor_THT:L_Toroid_Vertical_L13.0mm_W6.5mm_P5.60mm | ~
 |  | L2 | 300uH | Device:L_Ferrite | Inductor_THT:L_Toroid_Vertical_L16.0mm_W8.0mm_P7.62mm | ~
 |  | Q1 | BC547 | Transistor_BJT:BC547 | Package_TO_SOT_THT:TO-92_Inline | https://www.onsemi.com/pub/Collateral/BC550-D.pdf
 |  | Q2 | BC327 | :BC327_1 | Package_TO_SOT_THT:TO-92_Inline | http://www.onsemi.com/pub_link/Collateral/BC327-D.PDF
 |  | Q3 | BC327 | :BC327_2 | Package_TO_SOT_THT:TO-92_Inline | http://www.onsemi.com/pub_link/Collateral/BC327-D.PDF
 |  | Q4 | BC327 | Transistor_BJT:BC327 | Package_TO_SOT_THT:TO-92_Inline | http://www.onsemi.com/pub_link/Collateral/BC327-D.PDF
 |  | Q5 | TIP120 | Transistor_BJT:TIP120 | Package_TO_SOT_THT:TO-220-3_Vertical | https://www.onsemi.com/pub/Collateral/TIP120-D.PDF
 |  | Q6 | BC327 | Transistor_BJT:BC327 | Package_TO_SOT_THT:TO-92_Inline | http://www.onsemi.com/pub_link/Collateral/BC327-D.PDF
 |  | Q7 | BC557 | :BC557_1 | Package_TO_SOT_THT:TO-92_Inline | https://www.onsemi.com/pub/Collateral/BC556BTA-D.pdf
 |  | Q8 | BC557 | Transistor_BJT:BC557 | Package_TO_SOT_THT:TO-92_Inline | https://www.onsemi.com/pub/Collateral/BC556BTA-D.pdf
 |  | Q9 | BC557 | :BC557_1 | Package_TO_SOT_THT:TO-92_Inline | https://www.onsemi.com/pub/Collateral/BC556BTA-D.pdf
 |  | Q10 | BC557 | :BC557_2 | Package_TO_SOT_THT:TO-92_Inline | https://www.onsemi.com/pub/Collateral/BC556BTA-D.pdf
 |  | Q11 | BC557 | Transistor_BJT:BC557 | Package_TO_SOT_THT:TO-92_Inline | https://www.onsemi.com/pub/Collateral/BC556BTA-D.pdf
 |  | Q12 | BC547 | Transistor_BJT:BC547 | Package_TO_SOT_THT:TO-92_Inline | https://www.onsemi.com/pub/Collateral/BC550-D.pdf
 |  | Q13 | BC547 | Transistor_BJT:BC547 | Package_TO_SOT_THT:TO-92_Inline | https://www.onsemi.com/pub/Collateral/BC550-D.pdf
 |  | Q14 | BC547 | :BC547_1 | Package_TO_SOT_THT:TO-92_Inline | https://www.onsemi.com/pub/Collateral/BC550-D.pdf
 |  | Q15 | BC547 | :BC547_2 | Package_TO_SOT_THT:TO-92_Inline | https://www.onsemi.com/pub/Collateral/BC550-D.pdf
 |  | Q16 | BC547 | Transistor_BJT:BC547 | Package_TO_SOT_THT:TO-92_Inline | https://www.onsemi.com/pub/Collateral/BC550-D.pdf
 |  | R1 | 2K2 | Device:R | Resistor_THT:R_Axial_DIN0207_L6.3mm_D2.5mm_P10.16mm_Horizontal | ~
 |  | R2 | 100R | Device:R | Resistor_THT:R_Axial_DIN0207_L6.3mm_D2.5mm_P10.16mm_Horizontal | ~
 |  | R3 | 1K | Device:R | Resistor_THT:R_Axial_DIN0207_L6.3mm_D2.5mm_P10.16mm_Horizontal | ~
 |  | R4 | 4K7 | Device:R | Resistor_THT:R_Axial_DIN0207_L6.3mm_D2.5mm_P10.16mm_Horizontal | ~
 |  | R5 | 2K2 | Device:R | Resistor_THT:R_Axial_DIN0207_L6.3mm_D2.5mm_P10.16mm_Horizontal | ~
 |  | R6 | 2K2 | Device:R | Resistor_THT:R_Axial_DIN0207_L6.3mm_D2.5mm_P10.16mm_Horizontal | ~
 |  | R7 | 2K2 | Device:R | Resistor_THT:R_Axial_DIN0207_L6.3mm_D2.5mm_P10.16mm_Horizontal | ~
 |  | R8 | 1K | Device:R | Resistor_THT:R_Axial_DIN0207_L6.3mm_D2.5mm_P10.16mm_Horizontal | ~
 |  | R9 | 470R | Device:R | Resistor_THT:R_Axial_DIN0207_L6.3mm_D2.5mm_P10.16mm_Horizontal | ~
 |  | R10 | 330R | Device:R | Resistor_THT:R_Axial_DIN0207_L6.3mm_D2.5mm_P10.16mm_Horizontal | ~
 |  | R11 | 100R | Device:R | Resistor_THT:R_Axial_DIN0207_L6.3mm_D2.5mm_P10.16mm_Horizontal | ~
 |  | R12 | 2K2 | Device:R | Resistor_THT:R_Axial_DIN0207_L6.3mm_D2.5mm_P10.16mm_Horizontal | ~
 |  | R13 | 2K2 | Device:R | Resistor_THT:R_Axial_DIN0207_L6.3mm_D2.5mm_P10.16mm_Horizontal | ~
 |  | R14 | 10K | Device:R | Resistor_THT:R_Axial_DIN0207_L6.3mm_D2.5mm_P10.16mm_Horizontal | ~
 |  | R15 | 100R | Device:R | Resistor_THT:R_Axial_DIN0207_L6.3mm_D2.5mm_P10.16mm_Horizontal | ~
 |  | R16 | 220R | Device:R | Resistor_THT:R_Axial_DIN0207_L6.3mm_D2.5mm_P10.16mm_Horizontal | ~
 |  | R17 | 4K7 | Device:R | Resistor_THT:R_Axial_DIN0207_L6.3mm_D2.5mm_P10.16mm_Horizontal | ~
 |  | R18 | 2K2 | Device:R | Resistor_THT:R_Axial_DIN0207_L6.3mm_D2.5mm_P10.16mm_Horizontal | ~
 |  | R19 | 4K7 | Device:R | Resistor_THT:R_Axial_DIN0207_L6.3mm_D2.5mm_P10.16mm_Horizontal | ~
 |  | R20 | 3K9 | Device:R | Resistor_THT:R_Axial_DIN0207_L6.3mm_D2.5mm_P10.16mm_Horizontal | ~
 |  | R21 | 470R | Device:R | Resistor_THT:R_Axial_DIN0207_L6.3mm_D2.5mm_P10.16mm_Horizontal | ~
 |  | R22 | 1K | Device:R | Resistor_THT:R_Axial_DIN0207_L6.3mm_D2.5mm_P10.16mm_Horizontal | ~
 |  | R23 | 4K7 | Device:R | Resistor_THT:R_Axial_DIN0207_L6.3mm_D2.5mm_P10.16mm_Horizontal | ~
 |  | R24 | 4K7 | Device:R | Resistor_THT:R_Axial_DIN0207_L6.3mm_D2.5mm_P10.16mm_Horizontal | ~
 |  | R25 | 2K2 | Device:R | Resistor_THT:R_Axial_DIN0207_L6.3mm_D2.5mm_P10.16mm_Horizontal | ~
 |  | R26 | 2K2 | Device:R | Resistor_THT:R_Axial_DIN0207_L6.3mm_D2.5mm_P10.16mm_Horizontal | ~
 |  | R27 | 2K2 | Device:R | Resistor_THT:R_Axial_DIN0207_L6.3mm_D2.5mm_P10.16mm_Horizontal | ~
 |  | R28 | 2K2 | Device:R | Resistor_THT:R_Axial_DIN0207_L6.3mm_D2.5mm_P10.16mm_Horizontal | ~
 |  | R29 | 4K7 | Device:R | Resistor_THT:R_Axial_DIN0207_L6.3mm_D2.5mm_P10.16mm_Horizontal | ~
 |  | R30 | 4K7 | Device:R | Resistor_THT:R_Axial_DIN0207_L6.3mm_D2.5mm_P10.16mm_Horizontal | ~
 |  | R31 | 4K7 | Device:R | Resistor_THT:R_Axial_DIN0207_L6.3mm_D2.5mm_P10.16mm_Horizontal | ~
 |  | R32 | 10K | Device:R | Resistor_THT:R_Axial_DIN0207_L6.3mm_D2.5mm_P10.16mm_Horizontal | ~
 |  | R33 | 2K2 | Device:R | Resistor_THT:R_Axial_DIN0207_L6.3mm_D2.5mm_P10.16mm_Horizontal | ~
 |  | R34 | 470R | Device:R | Resistor_THT:R_Axial_DIN0207_L6.3mm_D2.5mm_P10.16mm_Horizontal | ~
 |  | R35 | 2K2 | Device:R | Resistor_THT:R_Axial_DIN0207_L6.3mm_D2.5mm_P10.16mm_Horizontal | ~
 |  | R36 | 470R | Device:R | Resistor_THT:R_Axial_DIN0207_L6.3mm_D2.5mm_P10.16mm_Horizontal | ~
 |  | R37 | 2K2 | Device:R | Resistor_THT:R_Axial_DIN0207_L6.3mm_D2.5mm_P10.16mm_Horizontal | ~
 |  | R38 | 2K2 | Device:R | Resistor_THT:R_Axial_DIN0207_L6.3mm_D2.5mm_P10.16mm_Horizontal | ~
 |  | R39 | 2K2 | Device:R | Resistor_THT:R_Axial_DIN0207_L6.3mm_D2.5mm_P10.16mm_Horizontal | ~
 |  | R40 | 100R | Device:R | Resistor_THT:R_Axial_DIN0207_L6.3mm_D2.5mm_P10.16mm_Horizontal | ~
 |  | R41 | 470R | Device:R | Resistor_THT:R_Axial_DIN0207_L6.3mm_D2.5mm_P10.16mm_Horizontal | ~
 |  | R42 | 2K2 | Device:R | Resistor_THT:R_Axial_DIN0207_L6.3mm_D2.5mm_P10.16mm_Horizontal | ~
 |  | R43 | 1K | Device:R | Resistor_THT:R_Axial_DIN0207_L6.3mm_D2.5mm_P10.16mm_Horizontal | ~
 |  | R44 | 4K7 | Device:R | Resistor_THT:R_Axial_DIN0207_L6.3mm_D2.5mm_P10.16mm_Horizontal | ~
 |  | R45 | 1K | Device:R | Resistor_THT:R_Axial_DIN0207_L6.3mm_D2.5mm_P10.16mm_Horizontal | ~
 |  | R46 | 4K7 | Device:R | Resistor_THT:R_Axial_DIN0207_L6.3mm_D2.5mm_P10.16mm_Horizontal | ~
 |  | R47 | 1K | Device:R | Resistor_THT:R_Axial_DIN0207_L6.3mm_D2.5mm_P10.16mm_Horizontal | ~
 |  | R48 | 1K | Device:R | Resistor_THT:R_Axial_DIN0207_L6.3mm_D2.5mm_P10.16mm_Horizontal | ~
 |  | R49 | 2K2 | Device:R | Resistor_THT:R_Axial_DIN0207_L6.3mm_D2.5mm_P10.16mm_Horizontal | ~
 |  | R50 | 2K2 | Device:R | Resistor_THT:R_Axial_DIN0207_L6.3mm_D2.5mm_P10.16mm_Horizontal | ~
 |  | R51 | 100R | Device:R | Resistor_THT:R_Axial_DIN0207_L6.3mm_D2.5mm_P10.16mm_Horizontal | ~
 |  | R52 | 560R | Device:R | Resistor_THT:R_Axial_DIN0207_L6.3mm_D2.5mm_P10.16mm_Horizontal | ~
 |  | U1 | 7809 | Regulator_Linear:LM7809_TO220 | Package_TO_SOT_THT:TO-220-3_Vertical | https://www.onsemi.cn/PowerSolutions/document/MC7800-D.PDF
 |  | U2 | 74LS06N | 74xx:74LS06N | Package_DIP:DIP-14_W7.62mm | http://www.ti.com/lit/gpn/sn74LS06N
 |  | U3 | Pico | MCU_RaspberryPi_and_Boards:Pico | MCU_RaspberryPi_and_Boards:RPi_Pico_SMD_TH
 |  | U4 | 74HC595 | 74xx:74HC595 | Package_DIP:DIP-16_W7.62mm | http://www.ti.com/lit/ds/symlink/sn74hc595.pdf
 |  | U5 | 74HC595 | 74xx:74HC595 | Package_DIP:DIP-16_W7.62mm | http://www.ti.com/lit/ds/symlink/sn74hc595.pdf
 |  | U6 | 74HC595 | 74xx:74HC595 | Package_DIP:DIP-16_W7.62mm | http://www.ti.com/lit/ds/symlink/sn74hc595.pdf
 |  | U7 | 74HC595 | 74xx:74HC595 | Package_DIP:DIP-16_W7.62mm | http://www.ti.com/lit/ds/symlink/sn74hc595.pdf
 |  | U8 | 74LS06N | 74xx:74LS06N | Package_DIP:DIP-14_W7.62mm | http://www.ti.com/lit/gpn/sn74LS06N
 |  | U9 | 74HC595 | 74xx:74HC595 | Package_DIP:DIP-16_W7.62mm | http://www.ti.com/lit/ds/symlink/sn74hc595.pdf
 |  | U10 | 74HC595 | 74xx:74HC595 | Package_DIP:DIP-16_W7.62mm | http://www.ti.com/lit/ds/symlink/sn74hc595.pdf
 |  | U11 | 74HC165 | 74xx:74HC165 | Package_DIP:DIP-16_W7.62mm | https://assets.nexperia.com/documents/data-sheet/74HC_HCT165.pdf
 |  | U12 | 74HC165 | 74xx:74HC165 | Package_DIP:DIP-16_W7.62mm | https://assets.nexperia.com/documents/data-sheet/74HC_HCT165.pdf
Collated Components:
Item | Qty | Reference(s) | Value | LibPart | Footprint | Datasheet
1 | 2 | C1, C2 | 10uF | Device:C_Polarized | Capacitor_THT:CP_Radial_D8.0mm_P3.50mm | ~
2 | 13 | C3, C5, C7, C9, C10, C11, C12, C13, C14, C15, C16, C17, C18 | 100nF | Device:C | Capacitor_THT:C_Disc_D6.0mm_W2.5mm_P5.00mm | ~
3 | 1 | C4 | 470uF | Device:C_Polarized | Capacitor_THT:CP_Radial_D10.0mm_P7.50mm | ~
4 | 1 | C6 | 22uF | Device:C_Polarized | Capacitor_THT:CP_Radial_D8.0mm_P3.50mm | ~
5 | 1 | C8 | 100uF | Device:C_Polarized | Capacitor_THT:C_Disc_D6.0mm_W2.5mm_P5.00mm | ~
6 | 3 | D1, D2, D4 | 1N4001 | Diode:1N4001 | Diode_THT:D_DO-41_SOD81_P10.16mm_Horizontal | http://www.vishay.com/docs/88503/1n4001.pdf
7 | 1 | D3 | GREEN | Device:LED | LED_THT:LED_D3.0mm | ~
8 | 3 | D5, D7, D11 | BAT46 | Diode:BAT46 | Diode_THT:D_DO-35_SOD27_P7.62mm_Horizontal | http://www.vishay.com/docs/85662/bat46.pdf
9 | 1 | D6 | RED | Device:LED | LED_THT:LED_D3.0mm | ~
10 | 2 | D8, D19 | 1N4733A | Diode:1N47xxA | Diode_THT:D_DO-41_SOD81_P10.16mm_Horizontal | https://www.vishay.com/docs/85816/1n4728a.pdf
11 | 8 | D9, D12, D13, D14, D15, D16, D17, D18 | 1N4148 | Diode:1N4148 | Diode_THT:D_DO-35_SOD27_P7.62mm_Horizontal | https://assets.nexperia.com/documents/data-sheet/1N4148_1N4448.pdf
12 | 1 | D10 | YELLOW | Device:LED | LED_THT:LED_D3.0mm | ~
13 | 1 | D20 | 1N4743A | Diode:1N47xxA | Diode_THT:D_DO-41_SOD81_P10.16mm_Horizontal | https://www.vishay.com/docs/85816/1n4728a.pdf
14 | 1 | J1 | 12-18V | Connector:Barrel_Jack_Switch | Connector_BarrelJack:BarrelJack_Horizontal | ~
15 | 1 | J2 | Parallel Adapter | Connector_Generic:Conn_02x24_Odd_Even | Connector_PinSocket_2.54mm:PinSocket_2x24_P2.54mm_Vertical | ~
16 | 1 | J3 | Serial Adapter | Connector_Generic:Conn_02x10_Odd_Even | Connector_PinSocket_2.54mm:PinSocket_2x10_P2.54mm_Vertical | ~
17 | 1 | L1 | 100uH | Device:L_Ferrite | Inductor_THT:L_Toroid_Vertical_L13.0mm_W6.5mm_P5.60mm | ~
18 | 1 | L2 | 300uH | Device:L_Ferrite | Inductor_THT:L_Toroid_Vertical_L16.0mm_W8.0mm_P7.62mm | ~
19 | 4 | Q1, Q12, Q13, Q16 | BC547 | Transistor_BJT:BC547 | Package_TO_SOT_THT:TO-92_Inline | https://www.onsemi.com/pub/Collateral/BC550-D.pdf
20 | 1 | Q2 | BC327 | :BC327_1 | Package_TO_SOT_THT:TO-92_Inline | http://www.onsemi.com/pub_link/Collateral/BC327-D.PDF
21 | 1 | Q3 | BC327 | :BC327_2 | Package_TO_SOT_THT:TO-92_Inline | http://www.onsemi.com/pub_link/Collateral/BC327-D.PDF
22 | 2 | Q4, Q6 | BC327 | Transistor_BJT:BC327 | Package_TO_SOT_THT:TO-92_Inline | http://www.onsemi.com/pub_link/Collateral/BC327-D.PDF
23 | 1 | Q5 | TIP120 | Transistor_BJT:TIP120 | Package_TO_SOT_THT:TO-220-3_Vertical | https://www.onsemi.com/pub/Collateral/TIP120-D.PDF
24 | 2 | Q7, Q9 | BC557 | :BC557_1 | Package_TO_SOT_THT:TO-92_Inline | https://www.onsemi.com/pub/Collateral/BC556BTA-D.pdf
25 | 2 | Q8, Q11 | BC557 | Transistor_BJT:BC557 | Package_TO_SOT_THT:TO-92_Inline | https://www.onsemi.com/pub/Collateral/BC556BTA-D.pdf
26 | 1 | Q10 | BC557 | :BC557_2 | Package_TO_SOT_THT:TO-92_Inline | https://www.onsemi.com/pub/Collateral/BC556BTA-D.pdf
27 | 1 | Q14 | BC547 | :BC547_1 | Package_TO_SOT_THT:TO-92_Inline | https://www.onsemi.com/pub/Collateral/BC550-D.pdf
28 | 1 | Q15 | BC547 | :BC547_2 | Package_TO_SOT_THT:TO-92_Inline | https://www.onsemi.com/pub/Collateral/BC550-D.pdf
29 | 19 | R1, R5, R6, R7, R12, R13, R18, R25, R26, R27, R28, R33, R35, R37, R38, R39, R42, R49, R50 | 2K2 | Device:R | Resistor_THT:R_Axial_DIN0207_L6.3mm_D2.5mm_P10.16mm_Horizontal | ~
30 | 5 | R2, R11, R15, R40, R51 | 100R | Device:R | Resistor_THT:R_Axial_DIN0207_L6.3mm_D2.5mm_P10.16mm_Horizontal | ~
31 | 7 | R3, R8, R22, R43, R45, R47, R48 | 1K | Device:R | Resistor_THT:R_Axial_DIN0207_L6.3mm_D2.5mm_P10.16mm_Horizontal | ~
32 | 10 | R4, R17, R19, R23, R24, R29, R30, R31, R44, R46 | 4K7 | Device:R | Resistor_THT:R_Axial_DIN0207_L6.3mm_D2.5mm_P10.16mm_Horizontal | ~
33 | 5 | R9, R21, R34, R36, R41 | 470R | Device:R | Resistor_THT:R_Axial_DIN0207_L6.3mm_D2.5mm_P10.16mm_Horizontal | ~
34 | 1 | R10 | 330R | Device:R | Resistor_THT:R_Axial_DIN0207_L6.3mm_D2.5mm_P10.16mm_Horizontal | ~
35 | 2 | R14, R32 | 10K | Device:R | Resistor_THT:R_Axial_DIN0207_L6.3mm_D2.5mm_P10.16mm_Horizontal | ~
36 | 1 | R16 | 220R | Device:R | Resistor_THT:R_Axial_DIN0207_L6.3mm_D2.5mm_P10.16mm_Horizontal | ~
37 | 1 | R20 | 3K9 | Device:R | Resistor_THT:R_Axial_DIN0207_L6.3mm_D2.5mm_P10.16mm_Horizontal | ~
38 | 1 | R52 | 560R | Device:R | Resistor_THT:R_Axial_DIN0207_L6.3mm_D2.5mm_P10.16mm_Horizontal | ~
39 | 1 | U1 | 7809 | Regulator_Linear:LM7809_TO220 | Package_TO_SOT_THT:TO-220-3_Vertical | https://www.onsemi.cn/PowerSolutions/document/MC7800-D.PDF
40 | 2 | U2, U8 | 74LS06N | 74xx:74LS06N | Package_DIP:DIP-14_W7.62mm | http://www.ti.com/lit/gpn/sn74LS06N
41 | 1 | U3 | Pico | MCU_RaspberryPi_and_Boards:Pico | MCU_RaspberryPi_and_Boards:RPi_Pico_SMD_TH
42 | 6 | U4, U5, U6, U7, U9, U10 | 74HC595 | 74xx:74HC595 | Package_DIP:DIP-16_W7.62mm | http://www.ti.com/lit/ds/symlink/sn74hc595.pdf
43 | 2 | U11, U12 | 74HC165 | 74xx:74HC165 | Package_DIP:DIP-16_W7.62mm | https://assets.nexperia.com/documents/data-sheet/74HC_HCT165.pdf

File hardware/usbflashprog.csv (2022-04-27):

Source: | E:\Users\Robson\Documentos\Pagina Robson\github\usbflashprog\hardware\usbflashprog.kicad_sch
Date: | 26/04/2022 20:40:26
Tool: | Eeschema (6.0.4)
Generator: | D:\Program Files\KiCad\bin\scripting\plugins/bom_csv_grouped_by_value.py
Component Count: | 123
Individual Components:
Item | Qty | Reference(s) | Value | LibPart | Footprint | Datasheet
 |  | C1 | 10uF | Device:C_Polarized | Capacitor_THT:CP_Radial_D5.0mm_P2.50mm | ~
 |  | C2 | 10uF | Device:C_Polarized | Capacitor_THT:CP_Radial_D5.0mm_P2.50mm | ~
 |  | C3 | 100nF | Device:C | Capacitor_THT:C_Disc_D5.0mm_W2.5mm_P2.50mm | ~
 |  | C4 | 470uF | Device:C_Polarized | Capacitor_THT:CP_Radial_D10.0mm_P2.50mm | ~
 |  | C5 | 100nF | Device:C | Capacitor_THT:C_Disc_D5.0mm_W2.5mm_P2.50mm | ~
 |  | C6 | 22uF | Device:C_Polarized | Capacitor_THT:CP_Radial_D5.0mm_P2.50mm | ~
 |  | C7 | 100nF | Device:C | Capacitor_THT:C_Disc_D5.0mm_W2.5mm_P2.50mm | ~
 |  | C8 | 100uF | Device:C_Polarized | Capacitor_THT:C_Disc_D5.0mm_W2.5mm_P2.50mm | ~
 |  | C9 | 100nF | Device:C | Capacitor_THT:C_Disc_D5.0mm_W2.5mm_P2.50mm | ~
 |  | C10 | 100nF | Device:C | Capacitor_THT:C_Disc_D5.0mm_W2.5mm_P2.50mm | ~
 |  | C11 | 100nF | Device:C | Capacitor_THT:C_Disc_D5.0mm_W2.5mm_P2.50mm | ~
 |  | C12 | 100nF | Device:C | Capacitor_THT:C_Disc_D5.0mm_W2.5mm_P2.50mm | ~
 |  | C13 | 100nF | Device:C | Capacitor_THT:C_Disc_D5.0mm_W2.5mm_P2.50mm | ~
 |  | C14 | 100nF | Device:C | Capacitor_THT:C_Disc_D5.0mm_W2.5mm_P2.50mm | ~
 |  | C15 | 100nF | Device:C | Capacitor_THT:C_Disc_D5.0mm_W2.5mm_P2.50mm | ~
 |  | C16 | 100nF | Device:C | Capacitor_THT:C_Disc_D5.0mm_W2.5mm_P2.50mm | ~
 |  | C17 | 100nF | Device:C | Capacitor_THT:C_Disc_D5.0mm_W2.5mm_P2.50mm | ~
 |  | C18 | 100nF | Device:C | Capacitor_THT:C_Disc_D5.0mm_W2.5mm_P2.50mm | ~
 |  | D1 | 1N4001 | Diode:1N4001 | Diode_THT:D_DO-41_SOD81_P10.16mm_Horizontal | http://www.vishay.com/docs/88503/1n4001.pdf
 |  | D2 | 1N4001 | Diode:1N4001 | Diode_THT:D_DO-41_SOD81_P10.16mm_Horizontal | http://www.vishay.com/docs/88503/1n4001.pdf
 |  | D3 | GREEN | Device:LED | LED_THT:LED_D3.0mm | ~
 |  | D4 | 1N4001 | Diode:1N4001 | Diode_THT:D_DO-41_SOD81_P10.16mm_Horizontal | http://www.vishay.com/docs/88503/1n4001.pdf
 |  | D5 | BAT46 | Diode:BAT46 | Diode_THT:D_DO-35_SOD27_P7.62mm_Horizontal | http://www.vishay.com/docs/85662/bat46.pdf
 |  | D6 | RED | Device:LED | LED_THT:LED_D3.0mm | ~
 |  | D7 | BAT46 | Diode:BAT46 | Diode_THT:D_DO-35_SOD27_P7.62mm_Horizontal | http://www.vishay.com/docs/85662/bat46.pdf
 |  | D8 | 1N4733A | Diode:1N47xxA | Diode_THT:D_DO-41_SOD81_P10.16mm_Horizontal | https://www.vishay.com/docs/85816/1n4728a.pdf
 |  | D9 | 1N4148 | Diode:1N4148 | Diode_THT:D_DO-35_SOD27_P7.62mm_Horizontal | https://assets.nexperia.com/documents/data-sheet/1N4148_1N4448.pdf
 |  | D10 | YELLOW | Device:LED | LED_THT:LED_D3.0mm | ~
 |  | D11 | BAT46 | Diode:BAT46 | Diode_THT:D_DO-35_SOD27_P7.62mm_Horizontal | http://www.vishay.com/docs/85662/bat46.pdf
 |  | D12 | 1N4148 | Diode:1N4148 | Diode_THT:D_DO-35_SOD27_P7.62mm_Horizontal | https://assets.nexperia.com/documents/data-sheet/1N4148_1N4448.pdf
 |  | D13 | 1N4148 | Diode:1N4148 | Diode_THT:D_DO-35_SOD27_P7.62mm_Horizontal | https://assets.nexperia.com/documents/data-sheet/1N4148_1N4448.pdf
 |  | D14 | 1N4148 | Diode:1N4148 | Diode_THT:D_DO-35_SOD27_P7.62mm_Horizontal | https://assets.nexperia.com/documents/data-sheet/1N4148_1N4448.pdf
 |  | D15 | 1N4148 | Diode:1N4148 | Diode_THT:D_DO-35_SOD27_P7.62mm_Horizontal | https://assets.nexperia.com/documents/data-sheet/1N4148_1N4448.pdf
 |  | D16 | 1N4148 | Diode:1N4148 | Diode_THT:D_DO-35_SOD27_P7.62mm_Horizontal | https://assets.nexperia.com/documents/data-sheet/1N4148_1N4448.pdf
 |  | D17 | 1N4148 | Diode:1N4148 | Diode_THT:D_DO-35_SOD27_P7.62mm_Horizontal | https://assets.nexperia.com/documents/data-sheet/1N4148_1N4448.pdf
 |  | D18 | 1N4148 | Diode:1N4148 | Diode_THT:D_DO-35_SOD27_P7.62mm_Horizontal | https://assets.nexperia.com/documents/data-sheet/1N4148_1N4448.pdf
 |  | D19 | 1N4733A | Diode:1N47xxA | Diode_THT:D_DO-41_SOD81_P10.16mm_Horizontal | https://www.vishay.com/docs/85816/1n4728a.pdf
 |  | D20 | 1N4743A | Diode:1N47xxA | Diode_THT:D_DO-41_SOD81_P10.16mm_Horizontal | https://www.vishay.com/docs/85816/1n4728a.pdf
 |  | J1 | 12-18V | Connector:Barrel_Jack_Switch | Connector_BarrelJack:BarrelJack_Horizontal | ~
 |  | J2 | Parallel Adapter | Connector_Generic:Conn_02x24_Odd_Even | Connector_PinHeader_2.54mm:PinHeader_2x24_P2.54mm_Vertical | ~
 |  | J3 | Serial Adapter | Connector_Generic:Conn_02x10_Odd_Even | Connector_PinHeader_2.54mm:PinHeader_2x10_P2.54mm_Vertical | ~
 |  | L1 | 100uH | Device:L_Ferrite | Inductor_THT:L_Toroid_Vertical_L13.0mm_W6.5mm_P5.60mm | ~
 |  | L2 | 300uH | Device:L_Ferrite | Inductor_THT:L_Toroid_Vertical_L16.0mm_W8.0mm_P7.62mm | ~
 |  | Q1 | BC547 | Transistor_BJT:BC547 | Package_TO_SOT_THT:TO-92_Inline | https://www.onsemi.com/pub/Collateral/BC550-D.pdf
 |  | Q2 | BC327 | :BC327_1 | Package_TO_SOT_THT:TO-92_Inline | http://www.onsemi.com/pub_link/Collateral/BC327-D.PDF
 |  | Q3 | BC327 | :BC327_2 | Package_TO_SOT_THT:TO-92_Inline | http://www.onsemi.com/pub_link/Collateral/BC327-D.PDF
 |  | Q4 | BC327 | Transistor_BJT:BC327 | Package_TO_SOT_THT:TO-92_Inline | http://www.onsemi.com/pub_link/Collateral/BC327-D.PDF
 |  | Q5 | TIP120 | Transistor_BJT:TIP120 | Package_TO_SOT_THT:TO-220-3_Vertical | https://www.onsemi.com/pub/Collateral/TIP120-D.PDF
 |  | Q6 | BC327 | Transistor_BJT:BC327 | Package_TO_SOT_THT:TO-92_Inline | http://www.onsemi.com/pub_link/Collateral/BC327-D.PDF
 |  | Q7 | BC557 | :BC557_1 | Package_TO_SOT_THT:TO-92_Inline | https://www.onsemi.com/pub/Collateral/BC556BTA-D.pdf
 |  | Q8 | BC557 | Transistor_BJT:BC557 | Package_TO_SOT_THT:TO-92_Inline | https://www.onsemi.com/pub/Collateral/BC556BTA-D.pdf
 |  | Q9 | BC557 | :BC557_1 | Package_TO_SOT_THT:TO-92_Inline | https://www.onsemi.com/pub/Collateral/BC556BTA-D.pdf
 |  | Q10 | BC557 | :BC557_2 | Package_TO_SOT_THT:TO-92_Inline | https://www.onsemi.com/pub/Collateral/BC556BTA-D.pdf
 |  | Q11 | BC557 | Transistor_BJT:BC557 | Package_TO_SOT_THT:TO-92_Inline | https://www.onsemi.com/pub/Collateral/BC556BTA-D.pdf
 |  | Q12 | BC547 | Transistor_BJT:BC547 | Package_TO_SOT_THT:TO-92_Inline | https://www.onsemi.com/pub/Collateral/BC550-D.pdf
 |  | Q13 | BC547 | Transistor_BJT:BC547 | Package_TO_SOT_THT:TO-92_Inline | https://www.onsemi.com/pub/Collateral/BC550-D.pdf
 |  | Q14 | BC547 | :BC547_1 | Package_TO_SOT_THT:TO-92_Inline | https://www.onsemi.com/pub/Collateral/BC550-D.pdf
 |  | Q15 | BC547 | :BC547_2 | Package_TO_SOT_THT:TO-92_Inline | https://www.onsemi.com/pub/Collateral/BC550-D.pdf
 |  | Q16 | BC547 | Transistor_BJT:BC547 | Package_TO_SOT_THT:TO-92_Inline | https://www.onsemi.com/pub/Collateral/BC550-D.pdf
 |  | R1 | 2K2 | Device:R | Resistor_THT:R_Axial_DIN0204_L3.6mm_D1.6mm_P7.62mm_Horizontal | ~
 |  | R2 | 100R | Device:R | Resistor_THT:R_Axial_DIN0204_L3.6mm_D1.6mm_P7.62mm_Horizontal | ~
 |  | R3 | 1K | Device:R | Resistor_THT:R_Axial_DIN0204_L3.6mm_D1.6mm_P7.62mm_Horizontal | ~
 |  | R4 | 4K7 | Device:R | Resistor_THT:R_Axial_DIN0204_L3.6mm_D1.6mm_P7.62mm_Horizontal | ~
 |  | R5 | 2K2 | Device:R | Resistor_THT:R_Axial_DIN0204_L3.6mm_D1.6mm_P7.62mm_Horizontal | ~
 |  | R6 | 2K2 | Device:R | Resistor_THT:R_Axial_DIN0204_L3.6mm_D1.6mm_P7.62mm_Horizontal | ~
 |  | R7 | 2K2 | Device:R | Resistor_THT:R_Axial_DIN0204_L3.6mm_D1.6mm_P7.62mm_Horizontal | ~
 |  | R8 | 1K | Device:R | Resistor_THT:R_Axial_DIN0204_L3.6mm_D1.6mm_P7.62mm_Horizontal | ~
 |  | R9 | 470R | Device:R | Resistor_THT:R_Axial_DIN0204_L3.6mm_D1.6mm_P7.62mm_Horizontal | ~
 |  | R10 | 330R | Device:R | Resistor_THT:R_Axial_DIN0204_L3.6mm_D1.6mm_P7.62mm_Horizontal | ~
 |  | R11 | 100R | Device:R | Resistor_THT:R_Axial_DIN0204_L3.6mm_D1.6mm_P7.62mm_Horizontal | ~
 |  | R12 | 2K2 | Device:R | Resistor_THT:R_Axial_DIN0204_L3.6mm_D1.6mm_P7.62mm_Horizontal | ~
 |  | R13 | 2K2 | Device:R | Resistor_THT:R_Axial_DIN0204_L3.6mm_D1.6mm_P7.62mm_Horizontal | ~
 |  | R14 | 10K | Device:R | Resistor_THT:R_Axial_DIN0204_L3.6mm_D1.6mm_P7.62mm_Horizontal | ~
 |  | R15 | 100R | Device:R | Resistor_THT:R_Axial_DIN0204_L3.6mm_D1.6mm_P7.62mm_Horizontal | ~
 |  | R16 | 220R | Device:R | Resistor_THT:R_Axial_DIN0204_L3.6mm_D1.6mm_P7.62mm_Horizontal | ~
 |  | R17 | 4K7 | Device:R | Resistor_THT:R_Axial_DIN0204_L3.6mm_D1.6mm_P7.62mm_Horizontal | ~
 |  | R18 | 2K2 | Device:R | Resistor_THT:R_Axial_DIN0204_L3.6mm_D1.6mm_P7.62mm_Horizontal | ~
 |  | R19 | 4K7 | Device:R | Resistor_THT:R_Axial_DIN0204_L3.6mm_D1.6mm_P7.62mm_Horizontal | ~
 |  | R20 | 3K9 | Device:R | Resistor_THT:R_Axial_DIN0204_L3.6mm_D1.6mm_P7.62mm_Horizontal | ~
 |  | R21 | 470R | Device:R | Resistor_THT:R_Axial_DIN0204_L3.6mm_D1.6mm_P7.62mm_Horizontal | ~
 |  | R22 | 1K | Device:R | Resistor_THT:R_Axial_DIN0204_L3.6mm_D1.6mm_P7.62mm_Horizontal | ~
 |  | R23 | 4K7 | Device:R | Resistor_THT:R_Axial_DIN0204_L3.6mm_D1.6mm_P7.62mm_Horizontal | ~
 |  | R24 | 4K7 | Device:R | Resistor_THT:R_Axial_DIN0204_L3.6mm_D1.6mm_P7.62mm_Horizontal | ~
 |  | R25 | 2K2 | Device:R | Resistor_THT:R_Axial_DIN0204_L3.6mm_D1.6mm_P7.62mm_Horizontal | ~
 |  | R26 | 2K2 | Device:R | Resistor_THT:R_Axial_DIN0204_L3.6mm_D1.6mm_P7.62mm_Horizontal | ~
 |  | R27 | 2K2 | Device:R | Resistor_THT:R_Axial_DIN0204_L3.6mm_D1.6mm_P7.62mm_Horizontal | ~
 |  | R28 | 2K2 | Device:R | Resistor_THT:R_Axial_DIN0204_L3.6mm_D1.6mm_P7.62mm_Horizontal | ~
 |  | R29 | 4K7 | Device:R | Resistor_THT:R_Axial_DIN0204_L3.6mm_D1.6mm_P7.62mm_Horizontal | ~
 |  | R30 | 4K7 | Device:R | Resistor_THT:R_Axial_DIN0204_L3.6mm_D1.6mm_P7.62mm_Horizontal | ~
 |  | R31 | 4K7 | Device:R | Resistor_THT:R_Axial_DIN0204_L3.6mm_D1.6mm_P7.62mm_Horizontal | ~
 |  | R32 | 10K | Device:R | Resistor_THT:R_Axial_DIN0204_L3.6mm_D1.6mm_P7.62mm_Horizontal | ~
 |  | R33 | 2K2 | Device:R | Resistor_THT:R_Axial_DIN0204_L3.6mm_D1.6mm_P7.62mm_Horizontal | ~
 |  | R34 | 470R | Device:R | Resistor_THT:R_Axial_DIN0204_L3.6mm_D1.6mm_P7.62mm_Horizontal | ~
 |  | R35 | 2K2 | Device:R | Resistor_THT:R_Axial_DIN0204_L3.6mm_D1.6mm_P7.62mm_Horizontal | ~
 |  | R36 | 470R | Device:R | Resistor_THT:R_Axial_DIN0204_L3.6mm_D1.6mm_P7.62mm_Horizontal | ~
 |  | R37 | 2K2 | Device:R | Resistor_THT:R_Axial_DIN0204_L3.6mm_D1.6mm_P7.62mm_Horizontal | ~
 |  | R38 | 2K2 | Device:R | Resistor_THT:R_Axial_DIN0204_L3.6mm_D1.6mm_P7.62mm_Horizontal | ~
 |  | R39 | 2K2 | Device:R | Resistor_THT:R_Axial_DIN0204_L3.6mm_D1.6mm_P7.62mm_Horizontal | ~
 |  | R40 | 100R | Device:R | Resistor_THT:R_Axial_DIN0204_L3.6mm_D1.6mm_P7.62mm_Horizontal | ~
 |  | R41 | 470R | Device:R | Resistor_THT:R_Axial_DIN0204_L3.6mm_D1.6mm_P7.62mm_Horizontal | ~
 |  | R42 | 2K2 | Device:R | Resistor_THT:R_Axial_DIN0204_L3.6mm_D1.6mm_P7.62mm_Horizontal | ~
 |  | R43 | 1K | Device:R | Resistor_THT:R_Axial_DIN0204_L3.6mm_D1.6mm_P7.62mm_Horizontal | ~
 |  | R44 | 4K7 | Device:R | Resistor_THT:R_Axial_DIN0204_L3.6mm_D1.6mm_P7.62mm_Horizontal | ~
 |  | R45 | 1K | Device:R | Resistor_THT:R_Axial_DIN0204_L3.6mm_D1.6mm_P7.62mm_Horizontal | ~
 |  | R46 | 4K7 | Device:R | Resistor_THT:R_Axial_DIN0204_L3.6mm_D1.6mm_P7.62mm_Horizontal | ~
 |  | R47 | 1K | Device:R | Resistor_THT:R_Axial_DIN0204_L3.6mm_D1.6mm_P7.62mm_Horizontal | ~
 |  | R48 | 1K | Device:R | Resistor_THT:R_Axial_DIN0204_L3.6mm_D1.6mm_P7.62mm_Horizontal | ~
 |  | R49 | 2K2 | Device:R | Resistor_THT:R_Axial_DIN0204_L3.6mm_D1.6mm_P7.62mm_Horizontal | ~
 |  | R50 | 2K2 | Device:R | Resistor_THT:R_Axial_DIN0204_L3.6mm_D1.6mm_P7.62mm_Horizontal | ~
 |  | R51 | 100R | Device:R | Resistor_THT:R_Axial_DIN0204_L3.6mm_D1.6mm_P7.62mm_Horizontal | ~
 |  | R52 | 560R | Device:R | Resistor_THT:R_Axial_DIN0204_L3.6mm_D1.6mm_P7.62mm_Horizontal | ~
 |  | U1 | 7809 | Regulator_Linear:LM7809_TO220 | Package_TO_SOT_THT:TO-220-3_Vertical | https://www.onsemi.cn/PowerSolutions/document/MC7800-D.PDF
 |  | U2 | 74LS06N | 74xx:74LS06N | Package_DIP:DIP-14_W7.62mm | http://www.ti.com/lit/gpn/sn74LS06N
 |  | U3 | Pico | MCU_RaspberryPi_and_Boards:Pico | MCU_RaspberryPi_and_Boards:RPi_Pico_SMD_TH
 |  | U4 | 74HC595 | 74xx:74HC595 | Package_DIP:DIP-16_W7.62mm | http://www.ti.com/lit/ds/symlink/sn74hc595.pdf
 |  | U5 | 74HC595 | 74xx:74HC595 | Package_DIP:DIP-16_W7.62mm | http://www.ti.com/lit/ds/symlink/sn74hc595.pdf
 |  | U6 | 74HC595 | 74xx:74HC595 | Package_DIP:DIP-16_W7.62mm | http://www.ti.com/lit/ds/symlink/sn74hc595.pdf
 |  | U7 | 74HC595 | 74xx:74HC595 | Package_DIP:DIP-16_W7.62mm | http://www.ti.com/lit/ds/symlink/sn74hc595.pdf
 |  | U8 | 74LS06N | 74xx:74LS06N | Package_DIP:DIP-14_W7.62mm | http://www.ti.com/lit/gpn/sn74LS06N
 |  | U9 | 74HC595 | 74xx:74HC595 | Package_DIP:DIP-16_W7.62mm | http://www.ti.com/lit/ds/symlink/sn74hc595.pdf
 |  | U10 | 74HC595 | 74xx:74HC595 | Package_DIP:DIP-16_W7.62mm | http://www.ti.com/lit/ds/symlink/sn74hc595.pdf
 |  | U11 | 74HC165 | 74xx:74HC165 | Package_DIP:DIP-16_W7.62mm | https://assets.nexperia.com/documents/data-sheet/74HC_HCT165.pdf
 |  | U12 | 74HC165 | 74xx:74HC165 | Package_DIP:DIP-16_W7.62mm | https://assets.nexperia.com/documents/data-sheet/74HC_HCT165.pdf
Collated Components:
Item | Qty | Reference(s) | Value | LibPart | Footprint | Datasheet
1 | 2 | C1, C2 | 10uF | Device:C_Polarized | Capacitor_THT:CP_Radial_D5.0mm_P2.50mm | ~
2 | 13 | C3, C5, C7, C9, C10, C11, C12, C13, C14, C15, C16, C17, C18 | 100nF | Device:C | Capacitor_THT:C_Disc_D5.0mm_W2.5mm_P2.50mm | ~
3 | 1 | C4 | 470uF | Device:C_Polarized | Capacitor_THT:CP_Radial_D10.0mm_P2.50mm | ~
4 | 1 | C6 | 22uF | Device:C_Polarized | Capacitor_THT:CP_Radial_D5.0mm_P2.50mm | ~
5 | 1 | C8 | 100uF | Device:C_Polarized | Capacitor_THT:C_Disc_D5.0mm_W2.5mm_P2.50mm | ~
6 | 3 | D1, D2, D4 | 1N4001 | Diode:1N4001 | Diode_THT:D_DO-41_SOD81_P10.16mm_Horizontal | http://www.vishay.com/docs/88503/1n4001.pdf
7 | 1 | D3 | GREEN | Device:LED | LED_THT:LED_D3.0mm | ~
8 | 3 | D5, D7, D11 | BAT46 | Diode:BAT46 | Diode_THT:D_DO-35_SOD27_P7.62mm_Horizontal | http://www.vishay.com/docs/85662/bat46.pdf
9 | 1 | D6 | RED | Device:LED | LED_THT:LED_D3.0mm | ~
10 | 2 | D8, D19 | 1N4733A | Diode:1N47xxA | Diode_THT:D_DO-41_SOD81_P10.16mm_Horizontal | https://www.vishay.com/docs/85816/1n4728a.pdf
11 | 8 | D9, D12, D13, D14, D15, D16, D17, D18 | 1N4148 | Diode:1N4148 | Diode_THT:D_DO-35_SOD27_P7.62mm_Horizontal | https://assets.nexperia.com/documents/data-sheet/1N4148_1N4448.pdf
12 | 1 | D10 | YELLOW | Device:LED | LED_THT:LED_D3.0mm | ~
13 | 1 | D20 | 1N4743A | Diode:1N47xxA | Diode_THT:D_DO-41_SOD81_P10.16mm_Horizontal | https://www.vishay.com/docs/85816/1n4728a.pdf
14 | 1 | J1 | 12-18V | Connector:Barrel_Jack_Switch | Connector_BarrelJack:BarrelJack_Horizontal | ~
15 | 1 | J2 | Parallel Adapter | Connector_Generic:Conn_02x24_Odd_Even | Connector_PinHeader_2.54mm:PinHeader_2x24_P2.54mm_Vertical | ~
16 | 1 | J3 | Serial Adapter | Connector_Generic:Conn_02x10_Odd_Even | Connector_PinHeader_2.54mm:PinHeader_2x10_P2.54mm_Vertical | ~
17 | 1 | L1 | 100uH | Device:L_Ferrite | Inductor_THT:L_Toroid_Vertical_L13.0mm_W6.5mm_P5.60mm | ~
18 | 1 | L2 | 300uH | Device:L_Ferrite | Inductor_THT:L_Toroid_Vertical_L16.0mm_W8.0mm_P7.62mm | ~
19 | 4 | Q1, Q12, Q13, Q16 | BC547 | Transistor_BJT:BC547 | Package_TO_SOT_THT:TO-92_Inline | https://www.onsemi.com/pub/Collateral/BC550-D.pdf
20 | 1 | Q2 | BC327 | :BC327_1 | Package_TO_SOT_THT:TO-92_Inline | http://www.onsemi.com/pub_link/Collateral/BC327-D.PDF
21 | 1 | Q3 | BC327 | :BC327_2 | Package_TO_SOT_THT:TO-92_Inline | http://www.onsemi.com/pub_link/Collateral/BC327-D.PDF
22 | 2 | Q4, Q6 | BC327 | Transistor_BJT:BC327 | Package_TO_SOT_THT:TO-92_Inline | http://www.onsemi.com/pub_link/Collateral/BC327-D.PDF
23 | 1 | Q5 | TIP120 | Transistor_BJT:TIP120 | Package_TO_SOT_THT:TO-220-3_Vertical | https://www.onsemi.com/pub/Collateral/TIP120-D.PDF
24 | 2 | Q7, Q9 | BC557 | :BC557_1 | Package_TO_SOT_THT:TO-92_Inline | https://www.onsemi.com/pub/Collateral/BC556BTA-D.pdf
25 | 2 | Q8, Q11 | BC557 | Transistor_BJT:BC557 | Package_TO_SOT_THT:TO-92_Inline | https://www.onsemi.com/pub/Collateral/BC556BTA-D.pdf
26 | 1 | Q10 | BC557 | :BC557_2 | Package_TO_SOT_THT:TO-92_Inline | https://www.onsemi.com/pub/Collateral/BC556BTA-D.pdf
27 | 1 | Q14 | BC547 | :BC547_1 | Package_TO_SOT_THT:TO-92_Inline | https://www.onsemi.com/pub/Collateral/BC550-D.pdf
28 | 1 | Q15 | BC547 | :BC547_2 | Package_TO_SOT_THT:TO-92_Inline | https://www.onsemi.com/pub/Collateral/BC550-D.pdf
29 | 19 | R1, R5, R6, R7, R12, R13, R18, R25, R26, R27, R28, R33, R35, R37, R38, R39, R42, R49, R50 | 2K2 | Device:R | Resistor_THT:R_Axial_DIN0204_L3.6mm_D1.6mm_P7.62mm_Horizontal | ~
30 | 5 | R2, R11, R15, R40, R51 | 100R | Device:R | Resistor_THT:R_Axial_DIN0204_L3.6mm_D1.6mm_P7.62mm_Horizontal | ~
31 | 7 | R3, R8, R22, R43, R45, R47, R48 | 1K | Device:R | Resistor_THT:R_Axial_DIN0204_L3.6mm_D1.6mm_P7.62mm_Horizontal | ~
32 | 10 | R4, R17, R19, R23, R24, R29, R30, R31, R44, R46 | 4K7 | Device:R | Resistor_THT:R_Axial_DIN0204_L3.6mm_D1.6mm_P7.62mm_Horizontal | ~
33 | 5 | R9, R21, R34, R36, R41 | 470R | Device:R | Resistor_THT:R_Axial_DIN0204_L3.6mm_D1.6mm_P7.62mm_Horizontal | ~
34 | 1 | R10 | 330R | Device:R | Resistor_THT:R_Axial_DIN0204_L3.6mm_D1.6mm_P7.62mm_Horizontal | ~
35 | 2 | R14, R32 | 10K | Device:R | Resistor_THT:R_Axial_DIN0204_L3.6mm_D1.6mm_P7.62mm_Horizontal | ~
36 | 1 | R16 | 220R | Device:R | Resistor_THT:R_Axial_DIN0204_L3.6mm_D1.6mm_P7.62mm_Horizontal | ~
37 | 1 | R20 | 3K9 | Device:R | Resistor_THT:R_Axial_DIN0204_L3.6mm_D1.6mm_P7.62mm_Horizontal | ~
38 | 1 | R52 | 560R | Device:R | Resistor_THT:R_Axial_DIN0204_L3.6mm_D1.6mm_P7.62mm_Horizontal | ~
39 | 1 | U1 | 7809 | Regulator_Linear:LM7809_TO220 | Package_TO_SOT_THT:TO-220-3_Vertical | https://www.onsemi.cn/PowerSolutions/document/MC7800-D.PDF
40 | 2 | U2, U8 | 74LS06N | 74xx:74LS06N | Package_DIP:DIP-14_W7.62mm | http://www.ti.com/lit/gpn/sn74LS06N
41 | 1 | U3 | Pico | MCU_RaspberryPi_and_Boards:Pico | MCU_RaspberryPi_and_Boards:RPi_Pico_SMD_TH
42 | 6 | U4, U5, U6, U7, U9, U10 | 74HC595 | 74xx:74HC595 | Package_DIP:DIP-16_W7.62mm | http://www.ti.com/lit/ds/symlink/sn74hc595.pdf
43 | 2 | U11, U12 | 74HC165 | 74xx:74HC165 | Package_DIP:DIP-16_W7.62mm | https://assets.nexperia.com/documents/data-sheet/74HC_HCT165.pdf

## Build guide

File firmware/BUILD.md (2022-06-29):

# usbflashprogUSB Flash/EPROM Programmer

A memory device programmer (Flash/EPROM/E2PROM) board and software, connected to PC by USB port.

## Build Instructions

Here are instructions on how to build the project.

## Contents

* [GNU/Linux&copy;](#gnulinux)
	* [Requirements](#requirements)
	* [Install Packages](#install-packages)
	* [Install Pico C SDK](#install-pico-c-sdk)
	* [Install Visual Studio Code \[Optional\]](#install-visual-studio-code-optional)
	* [Build](#build)
	* [Test \[Optional\]](#test-optional)
	* [Generate Code Coverage Report \[Optional\]](#generate-code-coverage-report-optional)
	* [Generate Doxygen Documentation \[Optional\]](#generate-doxygen-documentation-optional)
* [Microsoft Windows&copy;](#microsoft-windows)
	* [Requirements](#requirements)
	* [Install Git](#install-git)
	* [Install CMake](#install-cmake)
	* [Install GNU ARM Embedded Toolchain](#install-gnu-arm-embedded-toolchain)
	* [Install MSys2 and MinGW](#install-msys2-and-mingw)
	* [Install Python](#install-python)
	* [Install Pico C SDK](#install-pico-c-sdk)
	* [Install Doxygen \[Optional\]](#install-doxygen-optional)
	* [Install GraphViz \[Optional\]](#install-graphviz-optional)
	* [Install Visual Studio Code \[Optional\]](#install-visual-studio-code-optional)
	* [Update Environment Variables](#update-environment-variables)
	* [Build](#build)
	* [Debug \[Optional\]](#debug-optional)
	* [Generate Doxygen Documentation \[Optional\]](#generate-doxygen-documentation-optional)

## GNU/Linux&copy;

### Requirements

- GNU/Linux (tested with [Ubuntu Linux 22.04 LTS](https://releases.ubuntu.com/jammy/));
- Git ([Git 1:2.34.1-1ubuntu1.2](https://packages.ubuntu.com/jammy/git));
- CMake ([CMake 3.22.1-1ubuntu1](https://packages.ubuntu.com/jammy/cmake));
- GCC-ARM ([GCC-ARM 15:10.3-2021.07-4](https://packages.ubuntu.com/jammy/gcc-arm-none-eabi));
- GNU C/C++ Compiler ([GCC 4:11.2.0-1ubuntu1](https://packages.ubuntu.com/jammy/gcc));
- Pico C SDK Repository ([pico-sdk](https://github.com/raspberrypi/pico-sdk), ~80,5MB);
- LCov \[Optional\] ([LCov version 1.15-1](https://packages.ubuntu.com/jammy/lcov));
- Doxygen \[Optional\] ([Doxygen 1.9.1-2ubuntu2](https://packages.ubuntu.com/jammy/doxygen));
- GraphViz \[Optional\] ([GraphViz 2.42.2-6](https://packages.ubuntu.com/jammy/graphviz));
- Visual Studio Code \[Optional\] ([code_1.67.2-1652812855_amd64.deb](https://code.visualstudio.com/sha/download?build=stable&os=linux-deb-x64), ~78.9MB)

### Install Packages

1. Run the following commands:

```shell
sudo apt update
sudo apt install git cmake doxygen graphviz build-essential gcc-arm-none-eabi libstdc++-arm-none-eabi-newlib automake autoconf texinfo libtool libftdi-dev libusb-1.0-0-dev
```

### Install Pico C SDK

The Pico SDK contains a collection of tools and libraries used to facilitate development on the Raspberry Pi Pico (and other RP2040-enabled boards).
There is also a set of C examples in the official repositories that are useful demonstrations of how to use the SDK.

1. To install the required Pico C SDK, run the following commands:

```shell
cd ~
git clone -b master https://github.com/raspberrypi/pico-sdk.git
cd pico-sdk
git submodule update --init
cd ..
echo "export PICO_SDK_PATH=$HOME/pico-sdk" >> .bashrc
source .bashrc
```

### Install Visual Studio Code \[Optional\]

The purpose of this tutorial is to configure the popular cross-platform IDE Visual Studio Code, free and provided by Microsoft, to edit and compile the project.
However, you can use another IDE instead (like Eclipse, for example), or even not use any IDE.

To install Visual Studio Code:

1. Download the latest version from the [Visual Studio Code Site](https://code.visualstudio.com/).
The version installed at the time of writing this tutorial was [code_1.67.2-1652812855_amd64.deb](https://code.visualstudio.com/sha/download?build=stable&os=linux-deb-x64).

2. Run the following command:

```shell
sudo dpkg -i code_1.67.2-1652812855_amd64.deb
```

3. After installation, open Visual Studio Code and in the "Extensions tab", install the following extensions:
- CMake
- CMake Tools
- C/C++
- Cortex-Debug

### Build

1. Clone the project from the repository:

```shell
git clone https://github.com/robsonsmartins/usbflashprog.git
```

2. Change to `firmware/usbflashprog` directory:

```shell
cd usbflashprog/firmware/usbflashprog
```

3. Run the following commands:

```shell
mkdir build
cd build
cmake ..
make -j$(nproc)
```

4. The generated firmware binary will be in `build/` directory, with the filename `ufprog.uf2`.

### Test \[Optional\]]

1. Clone the project from the repository:

```shell
git clone https://github.com/robsonsmartins/usbflashprog.git
```

2. Change to `firmware/usbflashprog` directory:

```shell
cd usbflashprog/firmware/usbflashprog
```

3. Run the following commands:

```shell
mkdir build
cmake -B build -DCMAKE_BUILD_TYPE=Debug -DTEST_BUILD=ON ..
cmake --build build --config Debug
cd build
ctest -C Debug
```

### Generate Code Coverage Report \[Optional\]]

1. Clone the project from the repository:

```shell
git clone https://github.com/robsonsmartins/usbflashprog.git
```

2. Change to `firmware/usbflashprog` directory:

```shell
cd usbflashprog/firmware/usbflashprog
```

3. Run the following commands:

```shell
mkdir build
cmake -B build -DCMAKE_BUILD_TYPE=Debug -DTEST_BUILD=ON ..
cmake --build build --config Debug
cd build
ctest -C Debug
cd ..
lcov --directory ./build/ --capture --output-file ./build/coverage.info -rc lcov_branch_coverage=1 --exclude \/usr\/include\/\* --exclude \/usr\/local\/include\/\* --exclude .\/build\/\* --exclude .\/test\/\*
genhtml ./build/coverage.info --output-directory <output_dir>
```

### Generate Doxygen Documentation \[Optional\]

1. Clone the project from the repository:

```shell
git clone https://github.com/robsonsmartins/usbflashprog.git
```

2. Change to `firmware/usbflashprog` directory:

```shell
cd usbflashprog/firmware/usbflashprog
```

3. Run the following commands:

```shell
doxygen
```

The documentation is generated under `usbflashprog/docs/firmware/html` directory.

## Microsoft Windows&copy;

### Requirements

- Microsoft Windows&copy; 10 or above;
- Git ([Git-2.31.1-64-bit.exe](https://github.com/git-for-windows/git/releases/download/v2.31.1.windows.1/Git-2.31.1-64-bit.exe), ~47.5MB);
- CMake ([cmake-3.23.2-windows-x86_64.msi](https://github.com/Kitware/CMake/releases/download/v3.23.2/cmake-3.23.2-windows-x86_64.msi), ~27.9MB);
- GNU ARM Embedded Toolchain ([gcc-arm-none-eabi-10-2020-q4-major-win32.exe](https://developer.arm.com/-/media/Files/downloads/gnu-rm/10-2020q4/gcc-arm-none-eabi-10-2020-q4-major-win32.exe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), ~122MB);
- Python ([python-3.9.4-amd64.exe](https://www.python.org/ftp/python/3.9.4/python-3.9.4-amd64.exe), ~27MB);
- Pico C SDK Repository ([pico-sdk](https://github.com/raspberrypi/pico-sdk), ~80,5MB);
- MSys2/MinGW ([msys2-x86_64-20210419.exe](https://repo.msys2.org/distrib/x86_64/msys2-x86_64-20210419.exe), ~95.8MB);
- Doxygen \[Optional\] ([doxygen-1.9.4-setup.exe](https://www.doxygen.nl/files/doxygen-1.9.4-setup.exe), ~44.4MB);
- GraphViz \[Optional\] ([stable_windows_10_cmake_Release_x64_graphviz-install-2.47.1-win64.exe](https://gitlab.com/graphviz/graphviz/-/package_files/9574245/download), ~4.5MB);
- Visual Studio Code \[Optional\] ([VSCodeSetup-x64-1.55.1.exe](https://code.visualstudio.com/docs/?dv=win64), ~68.9MB)

### Install Git

Git makes downloading the code a lot easier, and the Windows version comes with Git Bash, which is a very useful shell that makes the Microsoft Windows command line a little more effective, like GNU/Linux.
It is even possible to change the default terminal from VS Code to Git Bash, making it more powerful and similar to GNU/Linux.

1. Download the latest Git SCM installer for Microsoft Windows from the [Git for Windows Downloads Page](https://git-scm.com/download/win).
In this tutorial the [Git-2.31.1-64-bit.exe](https://github.com/git-for-windows/git/releases/download/v2.31.1.windows.1/Git-2.31.1-64-bit.exe) version was used.

2. Run the installer. Use all default options.

3. When you get to the screen asking you to "choose a default editor", feel free to choose whatever you want.
A good option is [Notepad++](https://notepad-plus-plus.org/), and if you don't have it installed, you can select Notepad (Windows default), if you don't want to use an editor in console mode.

### Install CMake

CMake is a build utility, which helps to automate the process of building programs.
Unlike Make, it does not call the compiler/linker tools, but generates (platform dependent) file and directory structures needed to run Make.

1. Download the latest version of CMake from the official website: [CMake Downloads Page](https://cmake.org/download/).
The version used in this tutorial was [cmake-3.23.2-windows-x86_64.msi](https://github.com/Kitware/CMake/releases/download/v3.23.2/cmake-3.23.2-windows-x86_64.msi).

2. Run the installer and accept the user license.

3. Under "Install Options", select "Add CMake to the system PATH for all users".

4. In "Destination Folder", write a short and easy path, for example `c:\cmake`.

### Install GNU ARM Embedded Toolchain

The GNU ARM Embedded Toolchain package contains the set of ARM compilers needed to compile the C and C++ source code for the RP2040 microcontroller (present on the Raspberry Pi Pico).

1. Open the [GNU ARM Embedded Toolchain downloads page](https://developer.arm.com/tools-and-software/open-source-software/developer-tools/gnu-toolchain/gnu-rm/downloads), and download the latest installer for Windows.
At the time of writing this tutorial, the version used was [gcc-arm-none-eabi-10-2020-q4-major-win32.exe](https://developer.arm.com/-/media/Files/downloads/gnu-rm/10-2020q4/gcc-arm-none-eabi-10-2020-q4-major-win32.exe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).

2. Run the installer. When prompted, change the install location to a short and easy path, for example `c:\gcc-arm`.
The installer will automatically populate the destination folder with the name of the current version of the toolset.

3. Continue with the installation process. On the last screen, leave all options selected.

### Install MSys2 and MinGW

MSys2 is a collection of tools and libraries that provide an easy-to-use environment for building, installing and running native software for Microsoft Windows.
It offers a terminal (command line) similar to the GNU/Linux console, several standard POSIX and GNU commands and utilities, and a package installer similar to the Arch Linux distribution, Pacman.

1. To install MSys2, download the latest version of the installer package from [msys2.org](https://www.msys2.org/).
In this tutorial, the [msys2-x86_64-20210419.exe](https://repo.msys2.org/distrib/x86_64/msys2-x86_64-20210419.exe) version was used.

2. Run the installer. Enter the desired installation folder (short path with no accents, no spaces, no symlinks, no subdirectories or network drives).

3. When finished, check Run MSYS2 64bit now.

To install MinGW on MSys2, follow the steps:

1. First, update the package database and base packages. In the open console, run the command:

```shell
pacman -Syu
```

2. After closing the MSys2 console, reopen it through the shortcut in the Start Menu, and execute the commands:

```shell
pacman -Sy
pacman -Su
```

3. Install the packages for compilation by running the command:

```shell
pacman -S mingw-w64-x86_64-toolchain git make libtool pkg-config autoconf automake texinfo git
```

4. When asked which members to `mingw-w64-x86_64-toolchain` install, press __Enter__ to install them all (default).

5. When asked about a conflict between `pkg-config` and `pkgconf`, choose option Y (Remove pkgconf).

6. Downloading and installing the packages will take a long time.

7. To configure Path in MSys2:

- In the MSys2 terminal, open the file `~/.bashrc`, like this: `nano ~/.bashrc`.
- At the end of the file, add the line `PATH=${PATH}:/c/cmake/bin` (path of the cmake).
- Save the file <Ctrl + O> and close <Ctrl + X> the editor, and run `source ~/.bashrc`.

Now it will be possible to execute and get the return of `cmake --version`.

### Install Python

Pico's SDK needs Python to script and automate some of the build functions.

The Python version recommended in the [Raspberry Pi Pico Datasheet for the C/C++ SDK](https://datasheets.raspberrypi.org/pico/getting-started-with-pico.pdf) is 3.9 or higher.
Note that this version does not support Windows 7, and Python versions lower than this may not work with Pico.

1. Download the latest Python version installer from the [Python Downloads Page](https://www.python.org/downloads/).
The version used in this tutorial was [python-3.9.4-amd64.exe](https://www.python.org/ftp/python/3.9.4/python-3.9.4-amd64.exe).

2. Run the installer.
On the first screen, keep the "Install launcher for all users (recommended)" and "Add Python 3.9 to PATH" options checked.
Choose the "Customize installation" option.

3. Under "Optional Features", leave all options checked.
Under "Advanced Options", select "Install for all users", thus leaving the first 5 options checked.
In "Customize install location", type a short path as `C:\python`.

4. Click "Install Now" and wait for Python to install.

At the end of the installation process, select the "Disable path length limit" option.
If this option is not available, or if you leave it for later, it is important to manually disable the `MAX_PATH` length limit for the Pico SDK to work.
Pico's SDK (and other SDKs from other cards) often have long, nested directory trees, resulting in pathnames that exceed the original Windows limit (260 characters).

5. \[Optional\] If you haven't selected the "Disable path length limit" option in the Python installer, or want to do it manually:

- Run `regedit` (Windows Registry Editor);
- Open the subkey `Computer\HKEY_LOCAL_MACHINE\SYSTEM\CurrentControlSet\Control\FileSystem`;
- Add a value entry (if it doesn't already exist), with name `LongPathsEnabled`, of type `DWORD`;
- Change the value data to `1`;
- Before using the build tools for Pico, the computer must be restarted.

### Install Pico C SDK

The Pico SDK contains a collection of tools and libraries used to facilitate development on the Raspberry Pi Pico (and other RP2040-enabled boards).
There is also a set of C examples in the official repositories that are useful demonstrations of how to use the SDK.

1. To install the required Pico C SDK, run the following commands (inside MSys2):

```shell
cd $HOME
git clone -b master https://github.com/raspberrypi/pico-sdk.git
cd pico-sdk
git submodule update --init
cd ..
```

### Install Doxygen \[Optional\]

Doxygen is a tool designated for creating documentation (HTML, LATEX, Unix Man Pages, RTF or PostScript) from comments annotated in source code.
Supports multiple languages including C and C++.

Doxygen is not required to compile the binaries, but it can be useful if you want to generate the project's API documentation.

To install Doxygen:

1. Download the latest version for Windows from the [Doxygen Downloads Page](https://www.doxygen.nl/download.html).
The version used in this tutorial was [doxygen-1.9.4-setup.exe](https://www.doxygen.nl/files/doxygen-1.9.4-setup.exe).

2. Run the installer. When prompted, change the install location to a simple and easy path, such as `c:\doxygen`.

3. Install all components.

### Install GraphViz \[Optional\]

GraphViz is a software package capable of generating graphs from a programming API in languages such as C/C++, Python, C#, Ruby.
It's used by Doxygen to generate class diagrams, dependency between packages, etc.

GraphViz is not needed to compile binaries, and it only makes sense to install it if Doxygen is also installed.

To install GraphViz:

1. Download the latest version for Windows from the [GraphViz Downloads Page](https://graphviz.org/download/#windows).
The version used in this tutorial was [stable_windows_10_cmake_Release_x64_graphviz-install-2.47.1-win64.exe](https://gitlab.com/graphviz/graphviz/-/package_files/9574245/download).

2. When running the installer, under "Install Options", select the "Add Graphviz to the system PATH for all users" option.

3. When prompted, enter the installation location ("Destination Folder") for a short, easy path such as `c:\graphviz`.

### Install Visual Studio Code \[Optional\]

The purpose of this tutorial is to configure the popular cross-platform IDE Visual Studio Code, free and provided by Microsoft, to edit and compile the project.
However, you can use another IDE instead (like Eclipse, for example), or even not use any IDE.

To install Visual Studio Code:

1. Download the latest version from the [Visual Studio Code Site](https://code.visualstudio.com/).
The version installed at the time of writing this tutorial was [VSCodeSetup-x64-1.55.1.exe](https://code.visualstudio.com/docs/?dv=win64).

2. Visual Studio Code can be installed with all default options.

3. After installation, open Visual Studio Code and in the "Extensions tab", install the following extensions:
- CMake
- CMake Tools
- C/C++
- Qt tools

The "CMake Tools extension" must be configured to generate files for MinGW.

To do this:

1. Go to the CMake Tools extension settings, "Extension settings".

2. Find "CMake: Generator" field, and enter the value "MinGW Makefiles".

### Update Environment Variables

Some of the installed tools automatically update the Windows environment variables (specifically, the PATH).
However, some do not. Either way, this section helps you identify all the necessary variables.

To check and change environment variables, search the "Windows Search Bar" for the word "env".
Choose the option "Edit system environment variables", and click on "Environment variables...".

The following variables and inputs are required:

**`PATH`**
- `C:\msys\mingw64\bin`
- `C:\cmake\bin`
- `C:\gcc-arm\10 2020-q4-major\bin`
- `C:\Program Files\Git\cmd`
- `C:\python\Scripts\`
- `C:\python\`
- `C:\doxygen\bin` (if Doxygen was installed)
- `C:\graphviz\bin` (if GraphViz was installed)
- `C:\Program Files\Microsoft VS Code\bin` (if Visual Studio Code was installed)

**`PICO_SDK_PATH`**
- `%userprofile%\pico-sdk`

### Build

1. Clone the project from the repository (using the MSys2):

```shell
git clone https://github.com/robsonsmartins/usbflashprog.git
```

2. Change to `firmware/usbflashprog` directory:

```shell
cd usbflashprog/firmware/usbflashprog
```

3. Run the following commands:

```shell
mkdir build
cd build
cmake -G "MinGW Makefiles" ..
make -j$(nproc)
```

4. The generated firmware binary will be in `build/` directory, with the filename `ufprog.uf2`.

### Debug \[Optional\]

To debug the firmware follow the tutorial [Debugging the Raspberry Pi Pico in C/C++ with VS Code and MinGW for Windows (NO Build Tools for Visual Studio!)](https://www.robsonmartins.com/content/eletr/raspi/pico/csdkwind.php).

### Generate Doxygen Documentation \[Optional\]

1. Clone the project from the repository (using the Git Bash Shell):

```shell
git clone https://github.com/robsonsmartins/usbflashprog.git
```

2. Change to `firmware/usbflashprog` directory:

```shell
cd usbflashprog/firmware/usbflashprog
```

3. Run the following commands:

```shell
doxygen
```

The documentation is generated under `usbflashprog/docs/firmware/html` directory.

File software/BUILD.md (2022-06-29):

# usbflashprogUSB Flash/EPROM Programmer

A memory device programmer (Flash/EPROM/E2PROM) board and software, connected to PC by USB port.

## Build Instructions

Here are instructions on how to build the project.

## Contents

* [GNU/Linux&copy;](#gnulinux)
	* [Requirements](#requirements)
	* [Install Packages](#install-packages)
	* [Install Visual Studio Code \[Optional\]](#install-visual-studio-code-optional)
	* [Build](#build)
	* [Generate DEB Package \[Optional\]](#generate-deb-package-optional)
	* [Generate RPM Package \[Optional\]](#generate-rpm-package-optional)
	* [Generate Doxygen Documentation \[Optional\]](#generate-doxygen-documentation-optional)
* [Microsoft Windows&copy;](#microsoft-windows)
	* [Requirements](#requirements)
	* [Install Git](#install-git)
	* [Install CMake](#install-cmake)
	* [Install Qt and MinGW](#install-qt-and-mingw)
	* [Install Doxygen \[Optional\]](#install-doxygen-optional)
	* [Install GraphViz \[Optional\]](#install-graphviz-optional)
	* [Install Visual Studio Code \[Optional\]](#install-visual-studio-code-optional)
	* [Update Environment Variables](#update-environment-variables)
	* [Build](#build)
	* [Generate Installation Package \[Optional\]](#generate-installation-package-optional)
	* [Generate Doxygen Documentation \[Optional\]](#generate-doxygen-documentation-optional)

## GNU/Linux&copy;

### Requirements

- GNU/Linux (tested with [Ubuntu Linux 22.04 LTS](https://releases.ubuntu.com/jammy/));
- Git ([Git 1:2.34.1-1ubuntu1.2](https://packages.ubuntu.com/jammy/git));
- CMake ([CMake 3.22.1-1ubuntu1](https://packages.ubuntu.com/jammy/cmake));
- Qt ([Qt 5.15.3-1](https://packages.ubuntu.com/jammy/qttools5-dev-tools));
- GNU C/C++ Compiler ([GCC 4:11.2.0-1ubuntu1](https://packages.ubuntu.com/jammy/gcc));
- Doxygen \[Optional\] ([Doxygen 1.9.1-2ubuntu2](https://packages.ubuntu.com/jammy/doxygen));
- GraphViz \[Optional\] ([GraphViz 2.42.2-6](https://packages.ubuntu.com/jammy/graphviz));
- RPM \[Optional\] ([RPM 4.17.0+dfsg1-4build1](https://packages.ubuntu.com/jammy/rpm));
- Visual Studio Code \[Optional\] ([code_1.67.2-1652812855_amd64.deb](https://code.visualstudio.com/sha/download?build=stable&os=linux-deb-x64), ~78.9MB)

### Install Packages

1. Run the following commands:

```shell
sudo apt update
sudo apt install git cmake doxygen graphviz build-essential libglu1-mesa-dev libpulse-dev libglib2.0-dev
sudo apt --no-install-recommends install libqt*5-dev qt*5-dev libqt5waylandcompositor5-dev
```

### Install Visual Studio Code \[Optional\]

The purpose of this tutorial is to configure the popular cross-platform IDE Visual Studio Code, free and provided by Microsoft, to edit and compile the project.
However, you can use another IDE instead (like Eclipse, for example), or even not use any IDE.

To install Visual Studio Code:

1. Download the latest version from the [Visual Studio Code Site](https://code.visualstudio.com/).
The version installed at the time of writing this tutorial was [code_1.67.2-1652812855_amd64.deb](https://code.visualstudio.com/sha/download?build=stable&os=linux-deb-x64).

2. Run the following command:

```shell
sudo dpkg -i code_1.67.2-1652812855_amd64.deb
```

3. After installation, open Visual Studio Code and in the "Extensions tab", install the following extensions:
- CMake
- CMake Tools
- C/C++
- Qt tools

### Build

1. Clone the project from the repository:

```shell
git clone https://github.com/robsonsmartins/usbflashprog.git
```

2. Change to `software/usbflashprog` directory:

```shell
cd usbflashprog/software/usbflashprog
```

3. Run the following commands:

```shell
mkdir build
cd build
cmake ..
make -j$(nproc)
```

**Note**: If there is more than one version of the gcc/g++ compiler installed on the system, you can explicitly specify to CMake which compiler to use with the following command: 

```shell
cmake -DCMAKE_CXX_COMPILER=<full_path_of_compiler>/g++ ..
# e.g.: cmake -DCMAKE_CXX_COMPILER=/opt/gcc/8.1.0/bin/g++ ..
```

4. To run the program:

```shell
./ufprog
```

### Generate DEB Package \[Optional\]

1. Clone the project from the repository:

```shell
git clone https://github.com/robsonsmartins/usbflashprog.git
```

2. Change to `software/usbflashprog` directory:

```shell
cd usbflashprog/software/usbflashprog
```

3. Run the following commands:

```shell
mkdir build
cp -Rf "scripts/deb" "build/"
mkdir -p "build/deb/ufprog/opt/ufprog"
cp -f "build/ufprog" "build/deb/ufprog/opt/ufprog/"
cp -Rf "resources/linux/usr" "build/deb/ufprog/"
chmod 775 build/deb/ufprog/DEBIAN/*
chmod +x build/deb/ufprog/opt/ufprog/ufprog
cd build/deb
dpkg -b ufprog
mv ufprog.deb "../ufprog-`cat "../../VERSION"`-0-x86_64.deb"
```

4. The generated package will be `software/usbflashprog/build/ufprog-<version>-<architecture>.deb`.

### Generate RPM Package \[Optional\]

1. Clone the project from the repository:

```shell
git clone https://github.com/robsonsmartins/usbflashprog.git
```

2. Change to `software/usbflashprog` directory:

```shell
cd usbflashprog/software/usbflashprog
```

3. Run the following commands:

```shell
mkdir build
cp -Rf "scripts/rpm" "build/"
mkdir -p "build/rpm/ufprog/{BUILD,BUILDROOT,RPMS,SRPMS,SOURCES}"
mkdir -p "build/rpm/ufprog/SOURCES/opt/ufprog"
cp -f "build/ufprog" "build/rpm/ufprog/SOURCES/opt/ufprog/"
cp -Rf "resources/linux/usr" "build/rpm/ufprog/SOURCES/"
chmod 775 build/rpm/ufprog/SOURCES/*
chmod +x build/rpm/ufprog/SOURCES/opt/ufprog/ufprog
cd build/rpm/ufprog
sed -i "/^[[:space:]]*Version:/ s/:.*/: `cat "../../../VERSION"`/" SPECS/ufprog.spec
rpmbuild -bb SPECS/ufprog.spec
mv RPMS/x86_64/ufprog*.rpm ../../
```

4. The generated package will be `software/usbflashprog/build/ufprog-<version>.<architecture>.rpm`.

### Generate Doxygen Documentation \[Optional\]

1. Clone the project from the repository:

```shell
git clone https://github.com/robsonsmartins/usbflashprog.git
```

2. Change to `software/usbflashprog` directory:

```shell
cd usbflashprog/software/usbflashprog
```

3. Run the following commands:

```shell
doxygen
```

The documentation is generated under `usbflashprog/docs/software/html` directory.

## Microsoft Windows&copy;

### Requirements

- Microsoft Windows&copy; 10 or above;
- Git ([Git-2.31.1-64-bit.exe](https://github.com/git-for-windows/git/releases/download/v2.31.1.windows.1/Git-2.31.1-64-bit.exe), ~47.5MB);
- CMake ([cmake-3.23.2-windows-x86_64.msi](https://github.com/Kitware/CMake/releases/download/v3.23.2/cmake-3.23.2-windows-x86_64.msi), ~27.9MB);
- Qt and MinGW ([qt-opensource-windows-x86-5.12.12.exe](https://download.qt.io/official_releases/qt/5.12/5.12.12/qt-opensource-windows-x86-5.12.12.exe), ~3.7GB);
- Doxygen \[Optional\] ([doxygen-1.9.4-setup.exe](https://www.doxygen.nl/files/doxygen-1.9.4-setup.exe), ~44.4MB);
- GraphViz \[Optional\] ([stable_windows_10_cmake_Release_x64_graphviz-install-2.47.1-win64.exe](https://gitlab.com/graphviz/graphviz/-/package_files/9574245/download), ~4.5MB);
- Visual Studio Code \[Optional\] ([VSCodeSetup-x64-1.55.1.exe](https://code.visualstudio.com/docs/?dv=win64), ~68.9MB)

### Install Git

Git makes downloading the code a lot easier, and the Windows version comes with Git Bash, which is a very useful shell that makes the Microsoft Windows command line a little more effective, like GNU/Linux.
It is even possible to change the default terminal from VS Code to Git Bash, making it more powerful and similar to GNU/Linux.

1. Download the latest Git SCM installer for Microsoft Windows from the [Git for Windows Downloads Page](https://git-scm.com/download/win).
In this tutorial the [Git-2.31.1-64-bit.exe](https://github.com/git-for-windows/git/releases/download/v2.31.1.windows.1/Git-2.31.1-64-bit.exe) version was used.

2. Run the installer. Use all default options.

3. When you get to the screen asking you to "choose a default editor", feel free to choose whatever you want.
A good option is [Notepad++](https://notepad-plus-plus.org/), and if you don't have it installed, you can select Notepad (Windows default), if you don't want to use an editor in console mode.

### Install CMake

CMake is a build utility, which helps to automate the process of building programs.
Unlike Make, it does not call the compiler/linker tools, but generates (platform dependent) file and directory structures needed to run Make.

1. Download the latest version of CMake from the official website: [CMake Downloads Page](https://cmake.org/download/).
The version used in this tutorial was [cmake-3.23.2-windows-x86_64.msi](https://github.com/Kitware/CMake/releases/download/v3.23.2/cmake-3.23.2-windows-x86_64.msi).

2. Run the installer and accept the user license.

3. Under "Install Options", select "Add CMake to the system PATH for all users".

4. In "Destination Folder", write a short and easy path, for example `c:\cmake`.

### Install Qt and MinGW

MinGW (short for Minimalist GNU for Windows) is a collection of open source compilers and linkers, which allow you to build native applications (written in languages such as C and C++) for Microsoft Windows.

Qt is a C++ framework based on libraries and tools that enables the development of powerful, interactive, cross-platform applications and devices.

The installation of both tools is performed at once, through the following procedure:

1. Download the latest version of Qt5 from the official website: [Qt Downloads Page](https://www.qt.io/offline-installers).
The version used in this tutorial was [qt-opensource-windows-x86-5.12.12.exe](https://download.qt.io/official_releases/qt/5.12/5.12.12/qt-opensource-windows-x86-5.12.12.exe).

**Note**: Qt 6 is currently not supported by this project.

2. Run the installer.

3. Log in into your Qt account or create a new free account.

4. Accept the user license.

5. In "Destination Folder", write a short and easy path, for example `C:\Qt\5.12.12`.

6. In "Select Components", check the following:

- "Qt <version>" / "MinGW <version> 64-bit" (to build 64-bit binaries)
- "Qt <version>" / "MinGW <version> 32-bit" (to build 32-bit binaries)
- "Developer and Designer Tools" / "Qt Creator <version>"
- "Developer and Designer Tools" / "MinGW <version> 64-bit" (to build both 64-bit binaries)
- "Developer and Designer Tools" / "MinGW <version> 32-bit" (to build only 32-bit binaries)

7. Accept the user license, and other default options from installer.

8. To use the tools, it will be necessary to follow procedure [Update Environment Variables](#update-environment-variables).

### Install Doxygen \[Optional\]

Doxygen is a tool designated for creating documentation (HTML, LATEX, Unix Man Pages, RTF or PostScript) from comments annotated in source code.
Supports multiple languages including C and C++.

Doxygen is not required to compile the binaries, but it can be useful if you want to generate the project's API documentation.

To install Doxygen:

1. Download the latest version for Windows from the [Doxygen Downloads Page](https://www.doxygen.nl/download.html).
The version used in this tutorial was [doxygen-1.9.4-setup.exe](https://www.doxygen.nl/files/doxygen-1.9.4-setup.exe).

2. Run the installer. When prompted, change the install location to a simple and easy path, such as `c:\doxygen`.

3. Install all components.

### Install GraphViz \[Optional\]

GraphViz is a software package capable of generating graphs from a programming API in languages such as C/C++, Python, C#, Ruby.
It's used by Doxygen to generate class diagrams, dependency between packages, etc.

GraphViz is not needed to compile binaries, and it only makes sense to install it if Doxygen is also installed.

To install GraphViz:

1. Download the latest version for Windows from the [GraphViz Downloads Page](https://graphviz.org/download/#windows).
The version used in this tutorial was [stable_windows_10_cmake_Release_x64_graphviz-install-2.47.1-win64.exe](https://gitlab.com/graphviz/graphviz/-/package_files/9574245/download).

2. When running the installer, under "Install Options", select the "Add Graphviz to the system PATH for all users" option.

3. When prompted, enter the installation location ("Destination Folder") for a short, easy path such as `c:\graphviz`.

### Install Visual Studio Code \[Optional\]

The purpose of this tutorial is to configure the popular cross-platform IDE Visual Studio Code, free and provided by Microsoft, to edit and compile the project.
However, you can use another IDE instead (like Eclipse, for example), or even not use any IDE.

To install Visual Studio Code:

1. Download the latest version from the [Visual Studio Code Site](https://code.visualstudio.com/).
The version installed at the time of writing this tutorial was [VSCodeSetup-x64-1.55.1.exe](https://code.visualstudio.com/docs/?dv=win64).

2. Visual Studio Code can be installed with all default options.

3. After installation, open Visual Studio Code and in the "Extensions tab", install the following extensions:
- CMake
- CMake Tools
- C/C++
- Qt tools

The "CMake Tools extension" must be configured to generate files for MinGW.

To do this:

1. Go to the CMake Tools extension settings, "Extension settings".

2. Find "CMake: Generator" field, and enter the value "MinGW Makefiles".

### Update Environment Variables

Some of the installed tools automatically update the Windows environment variables (specifically, the PATH).
However, some do not. Either way, this section helps you identify all the necessary variables.

To check and change environment variables, search the "Windows Search Bar" for the word "env".
Choose the option "Edit system environment variables", and click on "Environment variables...".

The following variables and inputs are required:

**`PATH`**
- `C:\Qt\5.12.12\5.12.12\mingw73_64\bin`
- `C:\Qt\5.12.12\Tools\mingw730_64\bin`
- `C:\cmake\bin`
- `C:\Program Files\Git\cmd`
- `C:\doxygen\bin` (if Doxygen was installed)
- `C:\graphviz\bin` (if GraphViz was installed)
- `C:\Program Files\Microsoft VS Code\bin` (if Visual Studio Code was installed)

**`Qt5_DIR`**
- `C:\Qt\5.12.12\5.12.12\mingw73_64\lib\cmake\Qt5`

### Build

1. Clone the project from the repository (using the Git Bash Shell):

```shell
git clone https://github.com/robsonsmartins/usbflashprog.git
```

2. Change to `software/usbflashprog` directory:

```shell
cd usbflashprog/software/usbflashprog
```

3. Run the following commands:

```shell
mkdir build
cd build
cmake -G "MinGW Makefiles" .. -DCMAKE_BUILD_TYPE=Release
# or, for a debug version:
# cmake -G "MinGW Makefiles" .. -DCMAKE_BUILD_TYPE=Debug
make -j$(nproc)
```

**Note**: If there is more than one version of the MinGW compiler installed on the system, you can explicitly specify to CMake which compiler to use with the following command: 

```shell
cmake -G "MinGW Makefiles" -DCMAKE_CXX_COMPILER=<full_path_of_compiler>/g++.exe ..
# e.g.: cmake -G "MinGW Makefiles" -DCMAKE_CXX_COMPILER=/c/Qt/5.12.12/Tools/mingw730_64/bin/g++.exe ..
```

**Note**: If there is more than one version of the Qt installed on the system, you can explicitly specify to CMake which version to use with the following command: 

```shell
cmake -G "MinGW Makefiles" -DQt5_DIR=<path_of_qt_lib_cmake_qt5> ..
# e.g.: cmake -G "MinGW Makefiles" -DQt5_DIR=/c/Qt/5.12.12/5.12.12/mingw73_64/lib/cmake/Qt5 ..
```

4. To run the program:

```shell
./ufprog.exe
```

### Generate Installation Package \[Optional\]

1. Clone the project from the repository (using the Git Bash Shell):

```shell
git clone https://github.com/robsonsmartins/usbflashprog.git
```

2. Change to `software/usbflashprog/scripts` directory:

```shell
cd usbflashprog/software/usbflashprog/scripts
```

3. Run the following commands:

```shell
iscc.exe ufprog.iss
```

**Note**: To create a package for 32-bit OS, run the following command instead:

```shell
iscc.exe //Darch=win32 ufprog.iss
```

The install package is generated under `software/usbflashprog/build` subdirectory.

**Note**: The Qt executables and the compiler libraries are found with use of the Qt5_DIR variable.
To change this, run the following command instead:

```shell
iscc.exe //DQT_PATH=<path_of_qt> //DMINGW_PATH=<path_of_mingw> ufprog.iss
# e.g.: iscc.exe //DQT_PATH="d:\\Qt\\5.12.12\\5.12.12\\mingw73_32" //DMINGW_PATH="d:\\mingw73_32" ufprog.iss
```

### Generate Doxygen Documentation \[Optional\]

1. Clone the project from the repository (using the Git Bash Shell):

```shell
git clone https://github.com/robsonsmartins/usbflashprog.git
```

2. Change to `software/usbflashprog` directory:

```shell
cd usbflashprog/software/usbflashprog
```

3. Run the following commands:

```shell
doxygen
```

The documentation is generated under `usbflashprog/docs/software/html` directory.

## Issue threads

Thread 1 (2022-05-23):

Using the system ??

softfoot, 2022-05-23:
Sorry to leave this as an "issue" but I couldnt find any other way to contact someone re this intreaging project.
I am very interested in building this but cannot find any user docs (probably my fault).
Given that it plugs into a PC via USB - what software is run on the PC ??
I assume it may be just a serial emulator in which case where can I find the commands and arguments ??
If its a program on the PC - where can I find it ??
All the very best,
Dave

robsonsmartins, 2022-05-25:
Thanks for contacting Dave.

I updated the project status information in the [README](https://github.com/robsonsmartins/usbflashprog/blob/main/README.md).

As you can see, this project is under development, and at its current status, there is still no PC software or user documentation.

Currently, the effort is in validating the hardware specification, through a prototype, and developing the firmware for it.

If you have knowledge of Electronic Engineering or Firmware (C/C++) or Software (C++/Qt) Development, and want to contribute to the project, you can read the [CONTRIBUTING](https://github.com/robsonsmartins/usbflashprog/blob/main/CONTRIBUTING.md) file.

Regards,
Robson Martins

Closed 2022-05-25.

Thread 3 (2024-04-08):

AM29F support

red2211, 2024-04-08:
Hi, if I understood correctly, this programmer is able to r/w to AM28F flash. So my question is, can this programmer r/w an AM29F flash?
As I read the datasheet for AM28F and AM29F they are both similar in terms of r/w but the only difference I have noticed is voltage levels: AM28F has 12v, and AM29F has 5v.

robsonsmartins, 2024-04-08:
Yes, 29F flash will be supported. I remember that this project is in progress, and there is still a lot to add for version 1.0 to be released. I have currently frozen the software implementations to work on the PCB design, as the hardware prototype has been validated.

Closed 2024-04-08.

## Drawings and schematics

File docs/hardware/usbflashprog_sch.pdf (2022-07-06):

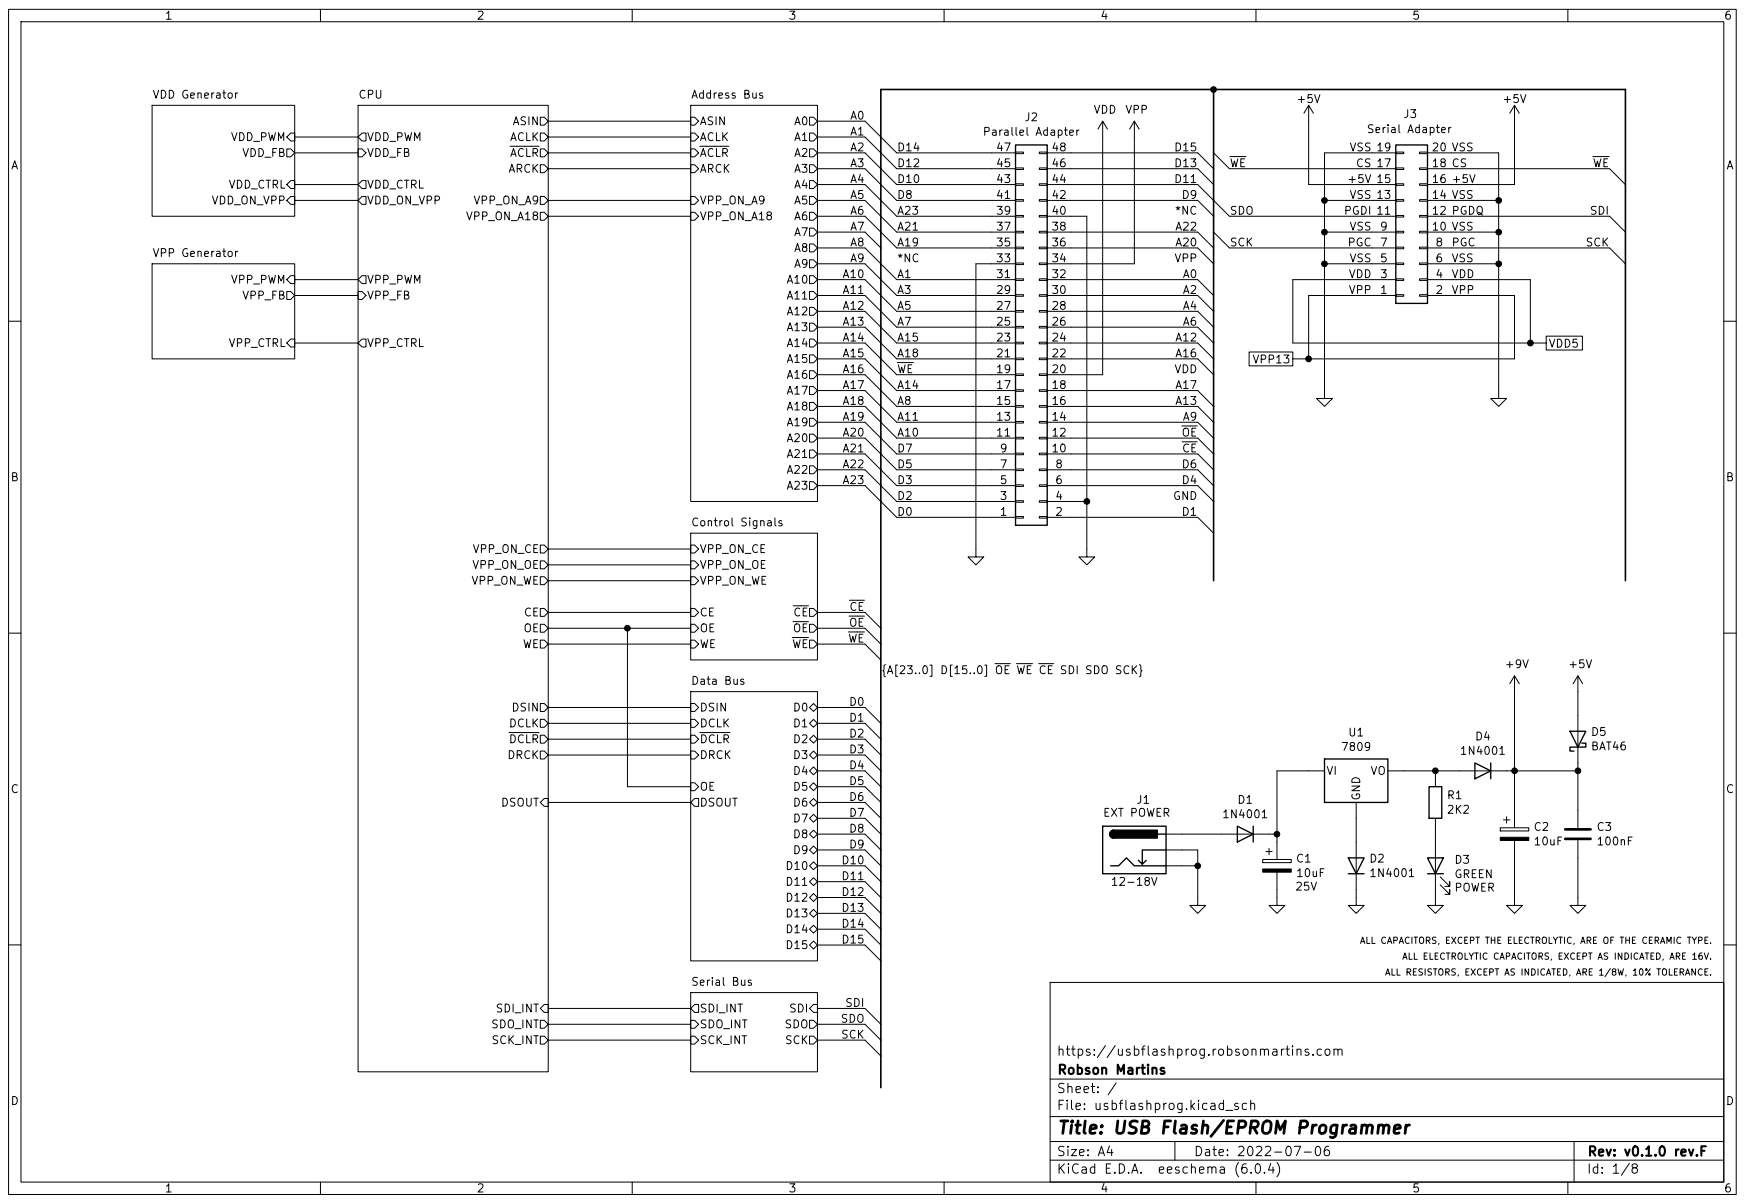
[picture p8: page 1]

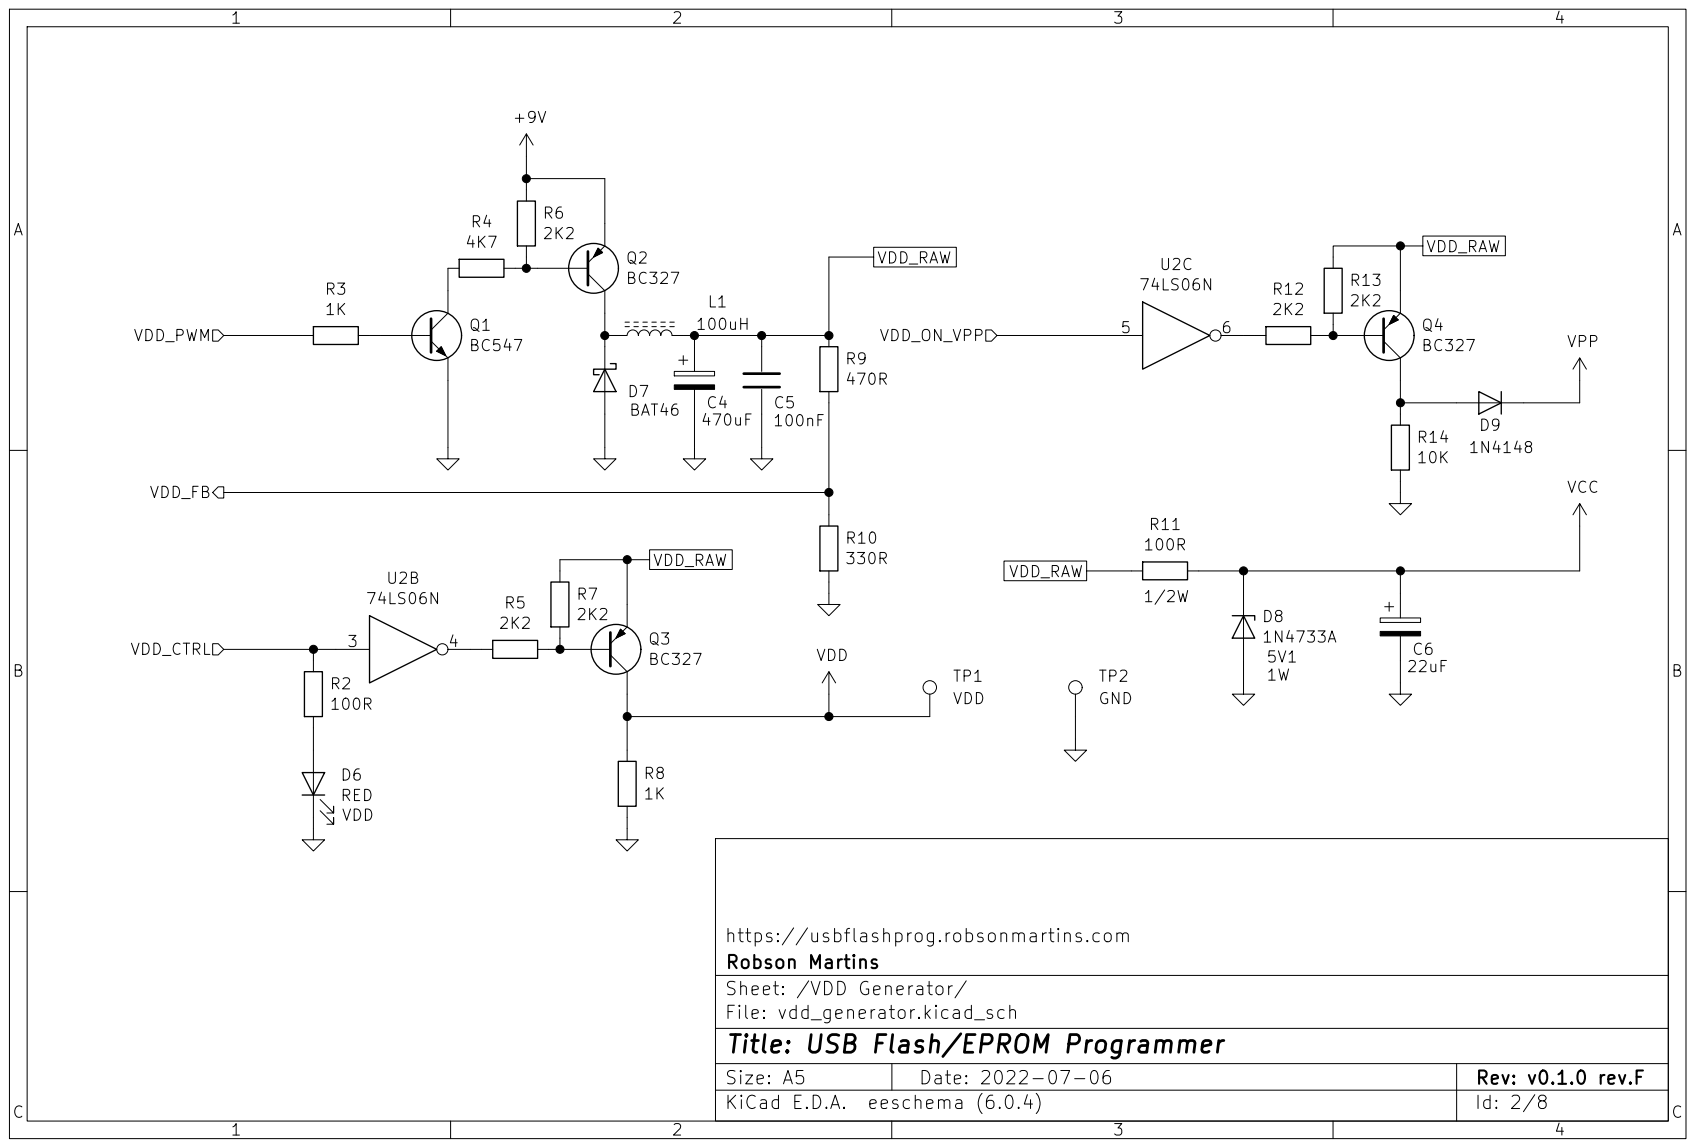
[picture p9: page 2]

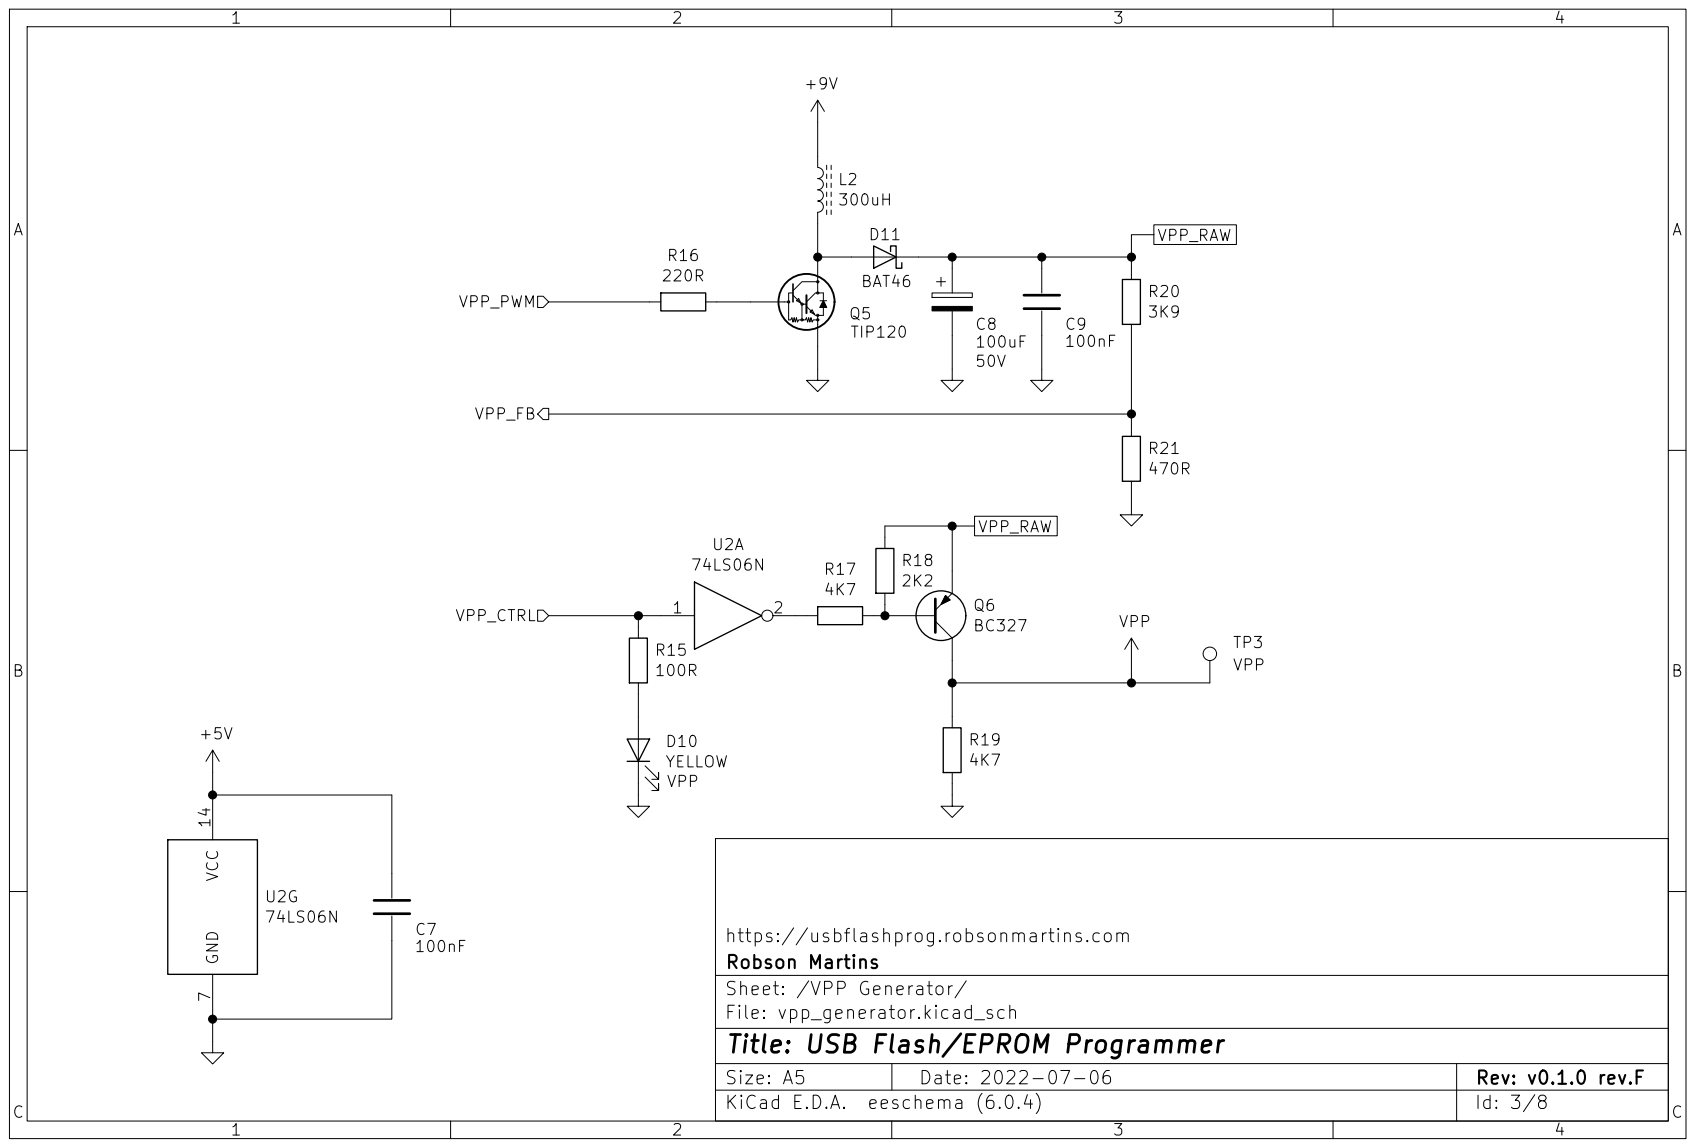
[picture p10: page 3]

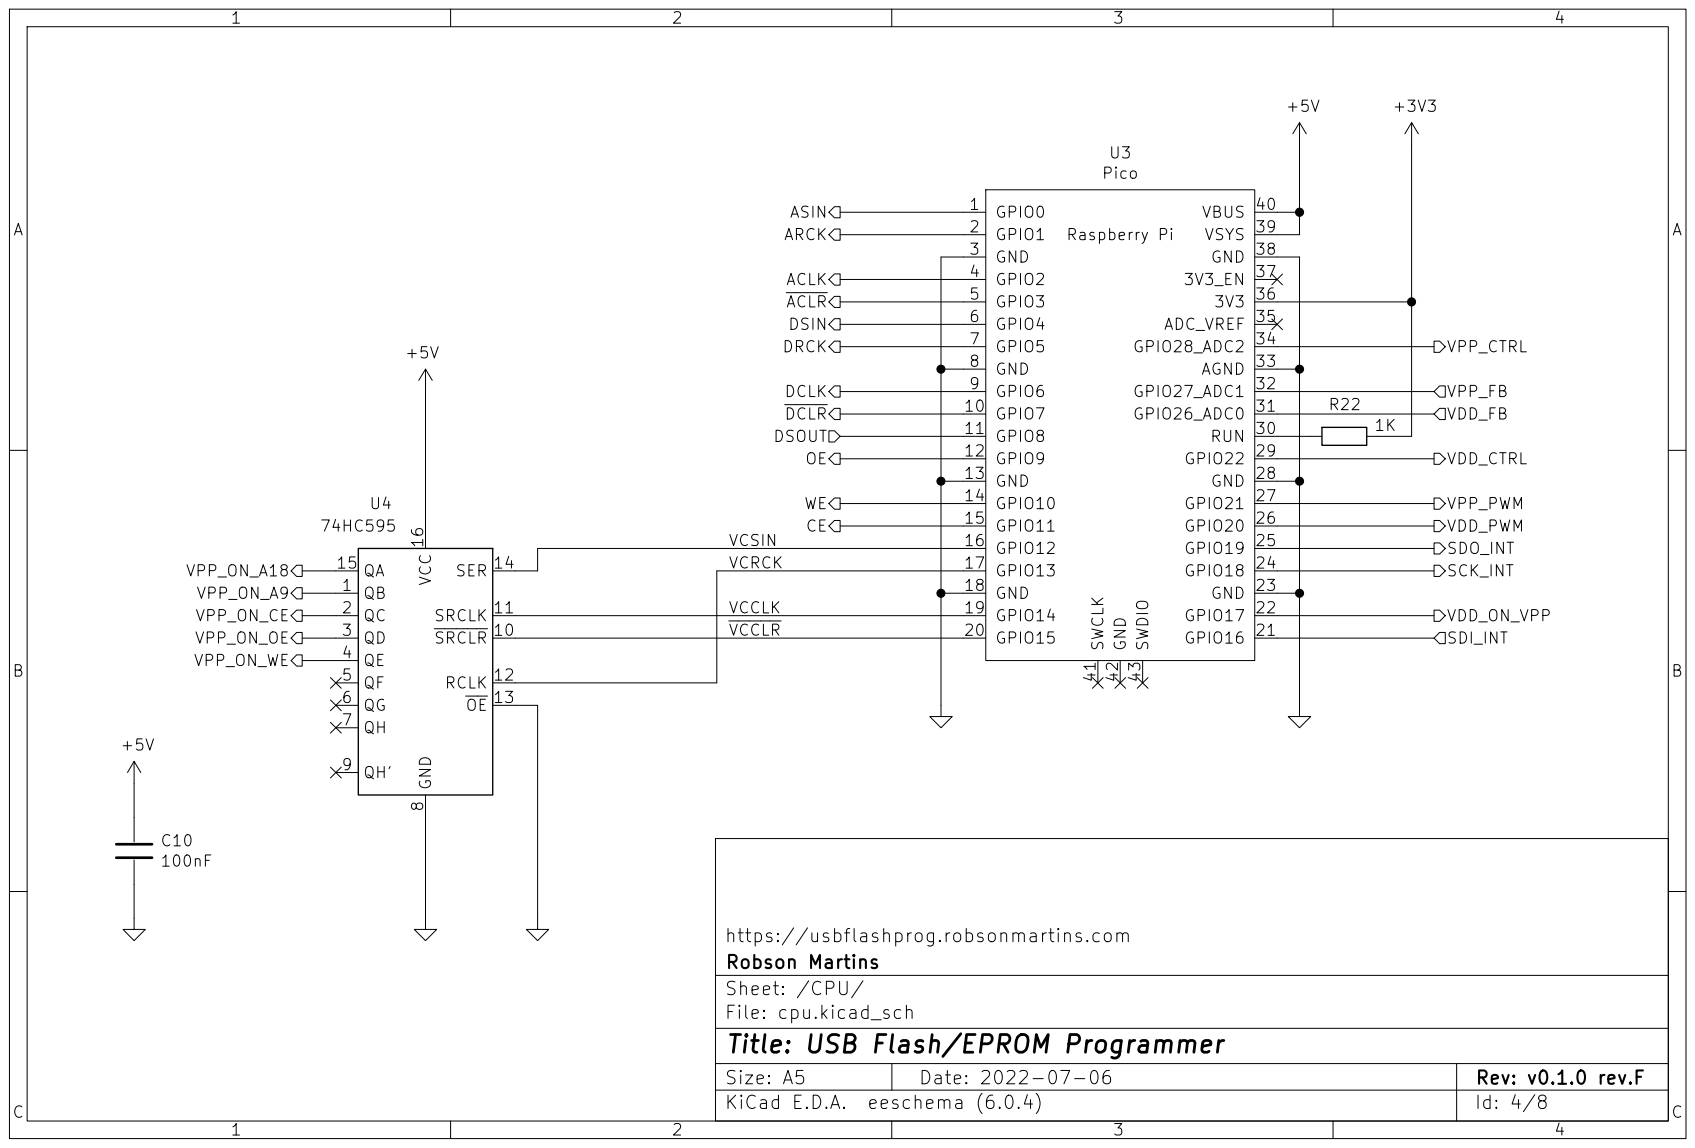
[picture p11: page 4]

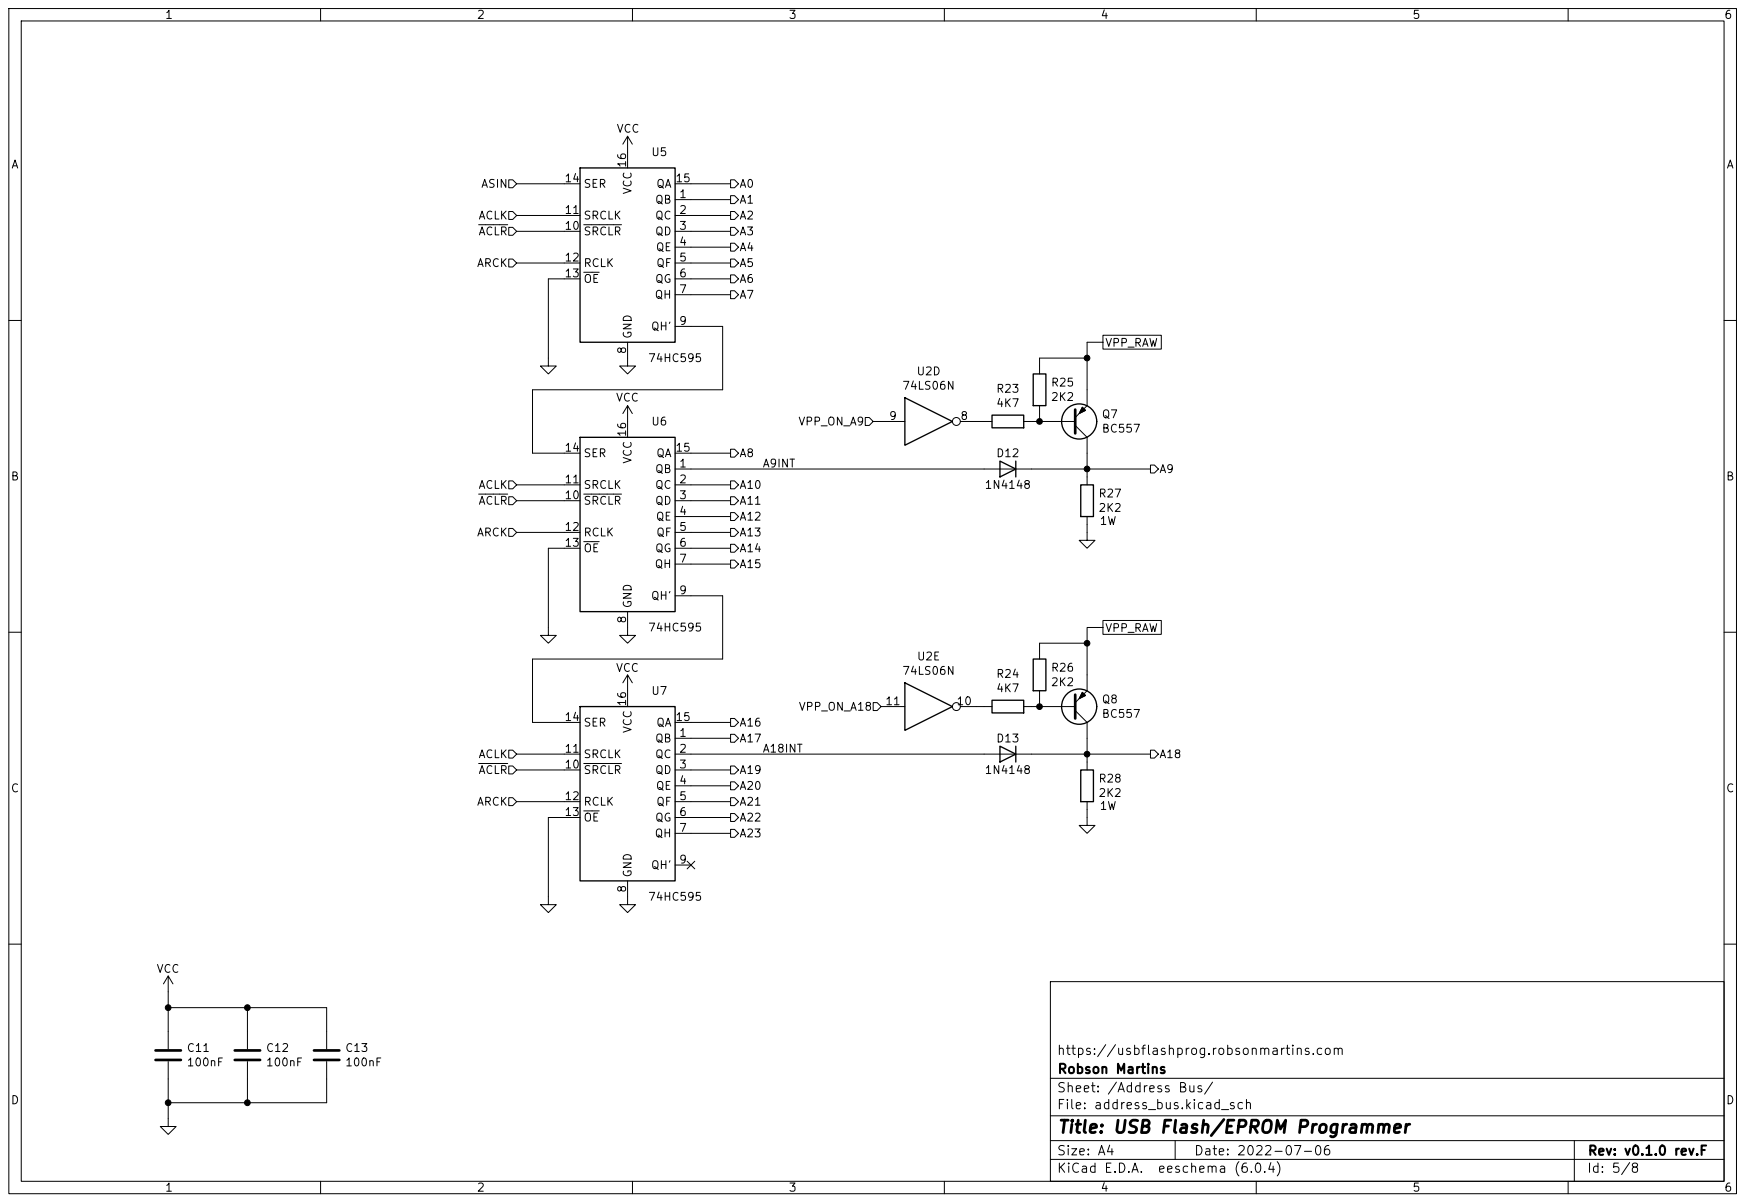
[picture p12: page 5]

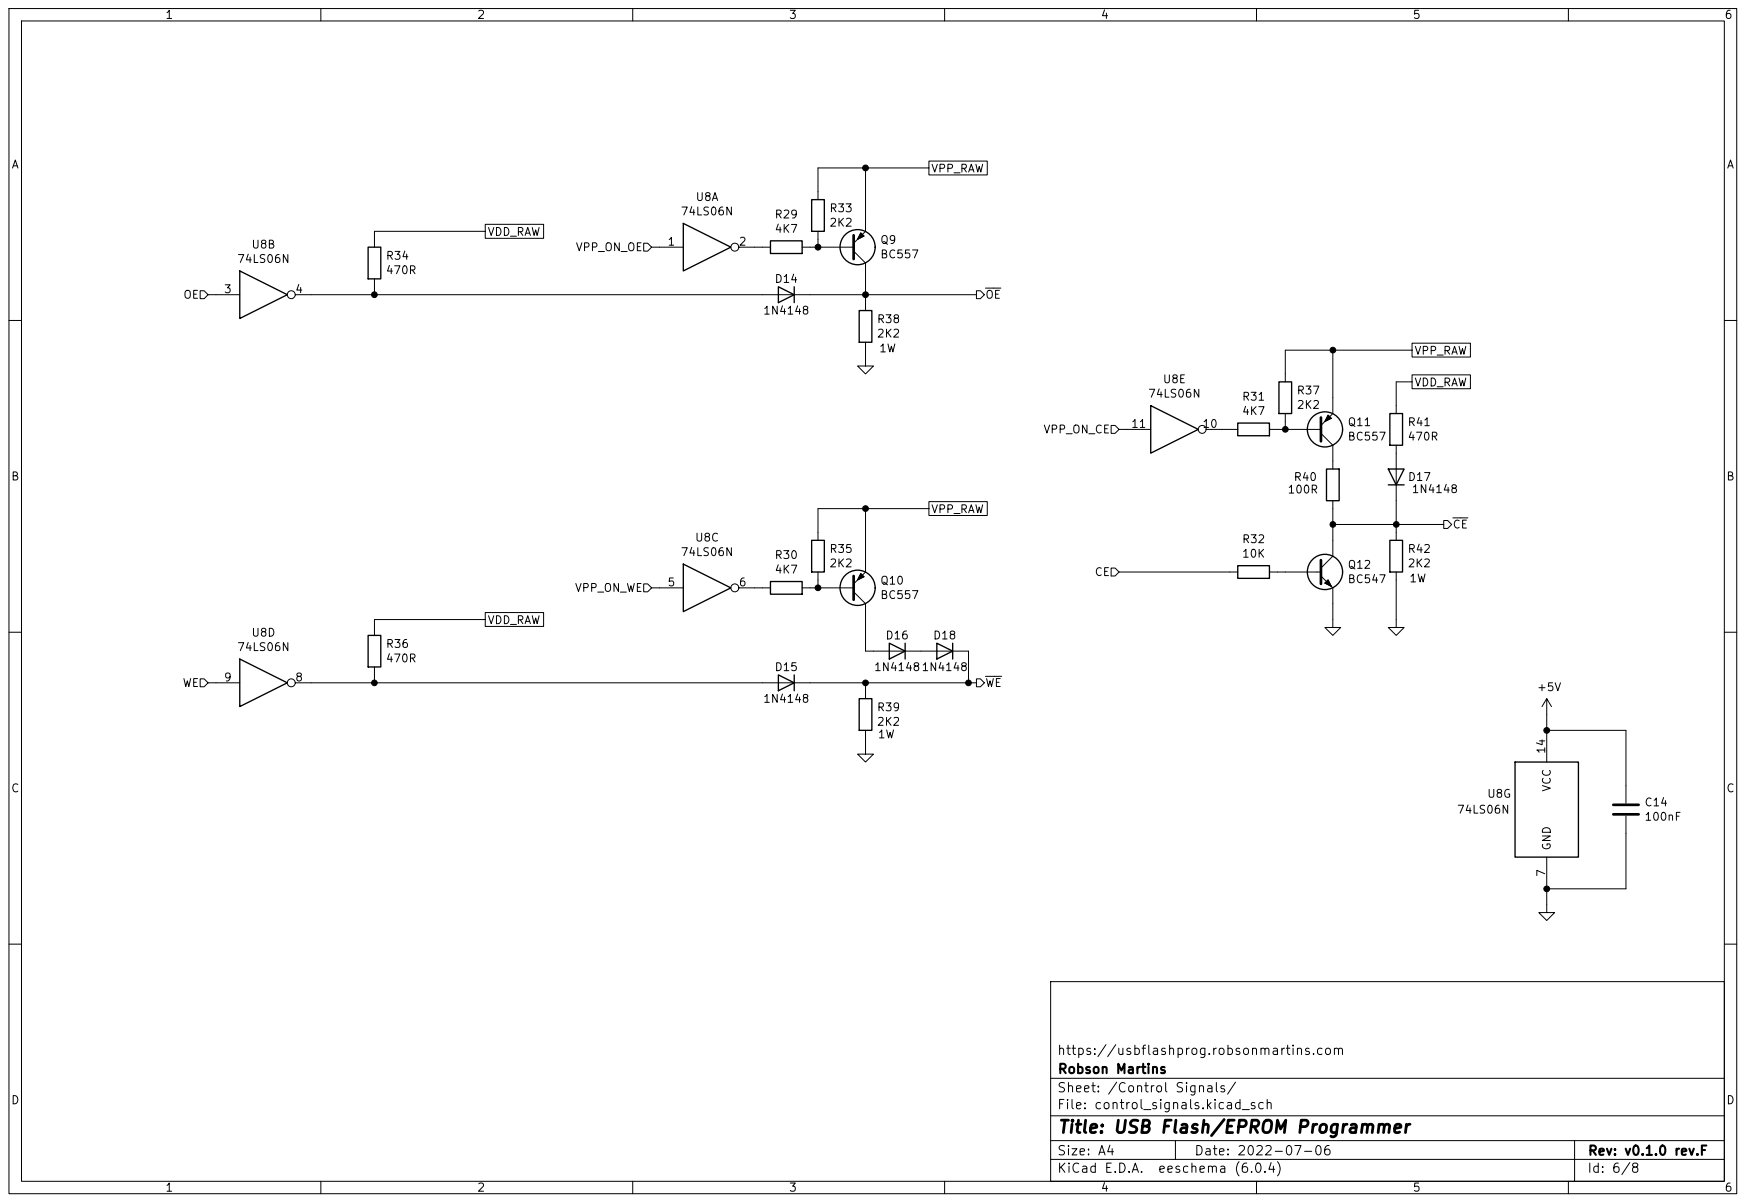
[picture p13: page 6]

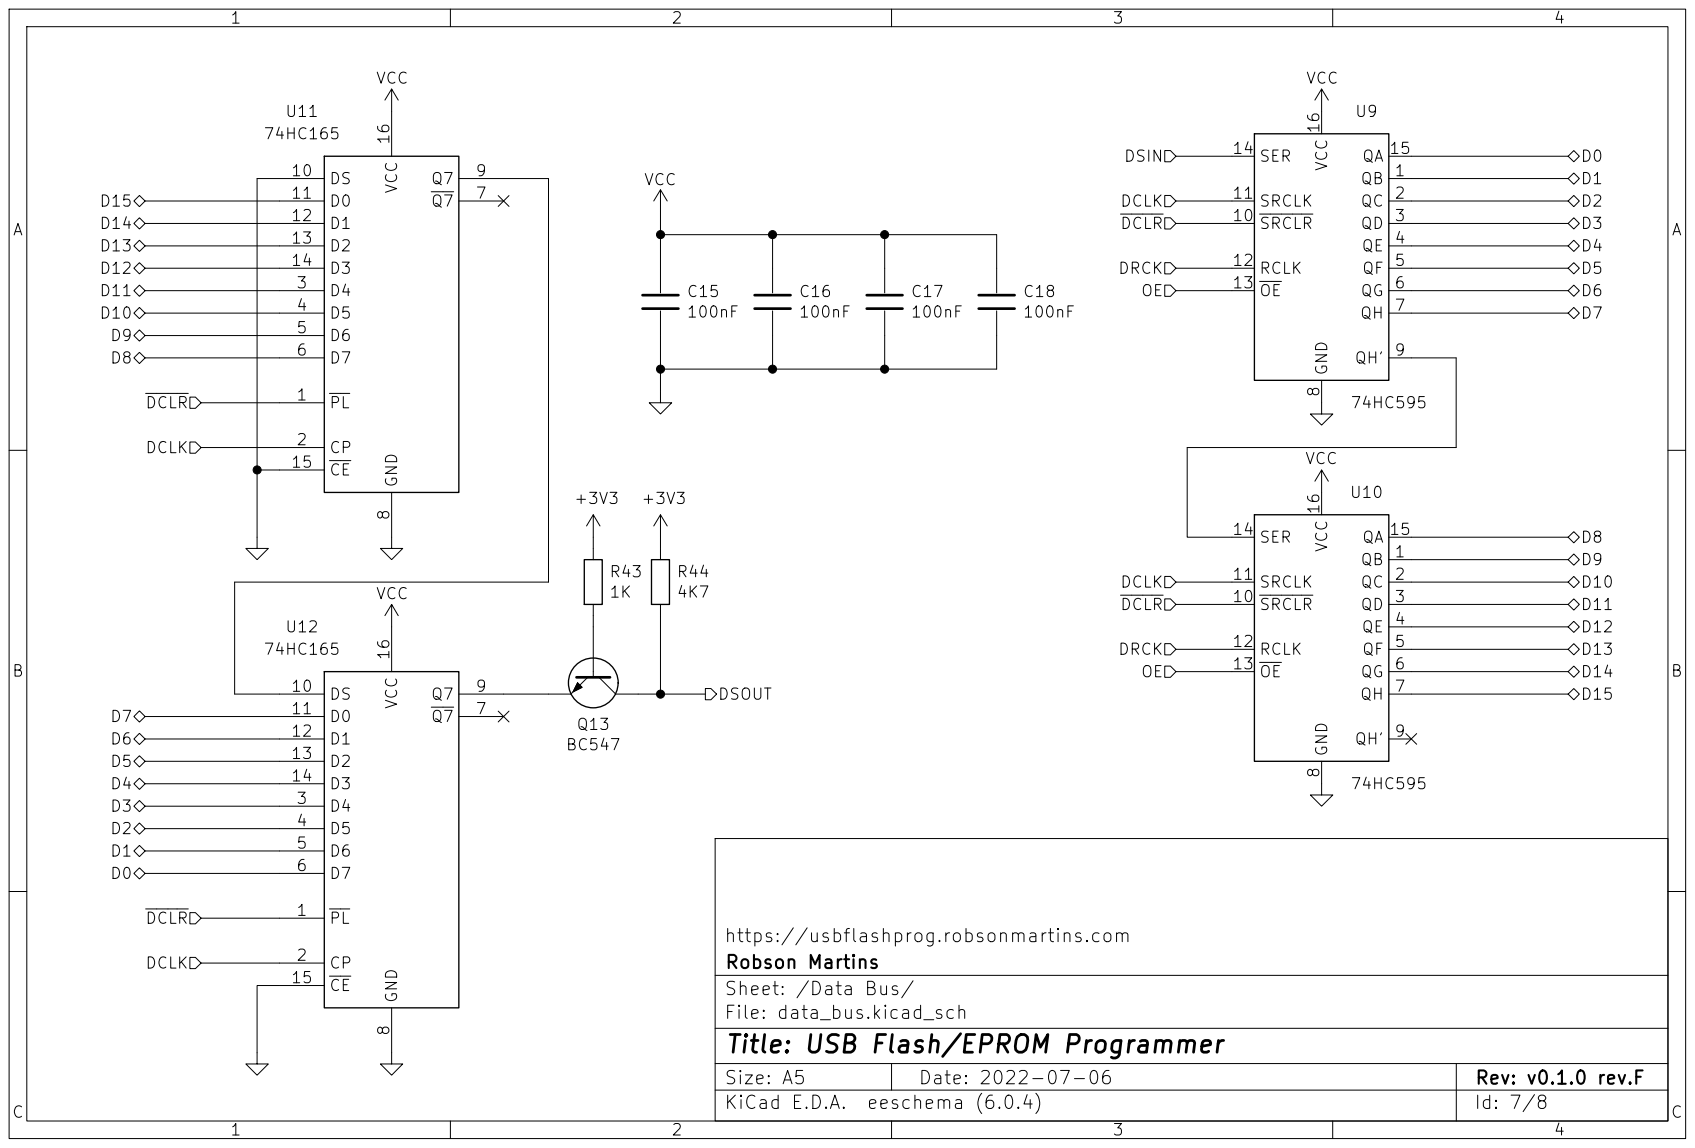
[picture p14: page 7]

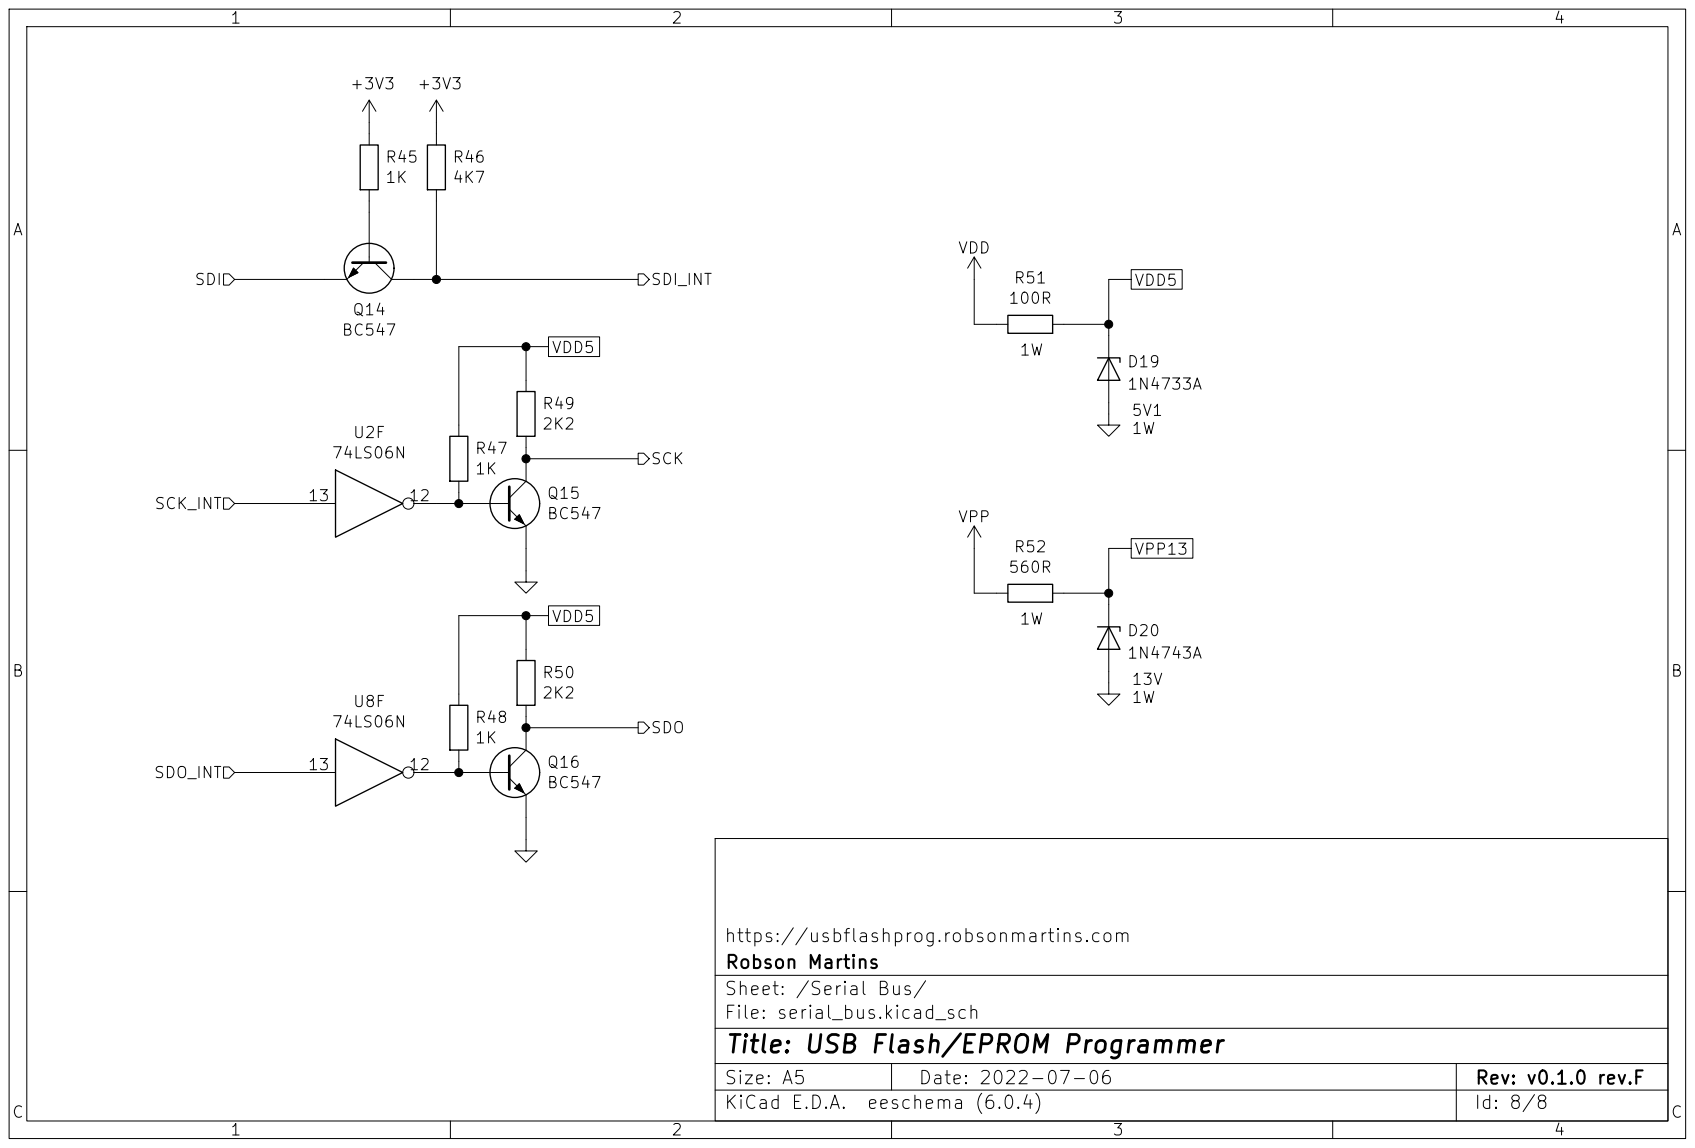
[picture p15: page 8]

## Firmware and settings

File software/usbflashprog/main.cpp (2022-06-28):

// ---------------------------------------------------------------------------
// USB EPROM/Flash Programmer
//
// Copyright (2022) Robson Martins
//
// This work is licensed under a Creative Commons Attribution-NonCommercial-
// ShareAlike 4.0 International License.
// ---------------------------------------------------------------------------
/** 
 * @defgroup Software Software Project
 * @brief    Software project for USB EPROM/Flash Programmer.
 */
// ---------------------------------------------------------------------------
/** 
 * @ingroup Software
 * @file main.cpp
 * @brief Implementation of the Main Routine.
 *  
 * @author Robson Martins (https://www.robsonmartins.com)
 */
// ---------------------------------------------------------------------------

#include <QApplication>
#include <QLocale>
#include <QTranslator>
#include <cstdlib>

#include "main/mainwindow.hpp"
#include "diag/diagwindow.hpp"
#include "config.hpp"

// ---------------------------------------------------------------------------

/**
 * @brief Main routine.
 * @param argc Number of arguments.
 * @param argv Array of arguments.
 * @return Error code (zero if success).
 */
int main(int argc, char *argv[]);

/**
 * @brief Creates a QMainWindow object, according to the arguments
 *  passed on the command line.
 * @param argc Number of arguments.
 * @param argv Array of arguments.
 * @return Pointer to the QMainWindow object.
 */
QMainWindow* createWindow(const int &argc, char *argv[]);

// ---------------------------------------------------------------------------

QMainWindow* createWindow(const int &argc, char *argv[]) {
    /*
    for (int i = 1; i < argc; ++i) {
        if (!qstrcmp(argv[i], "--diag")) {
            return new DiagWindow();
        }
    }
    return new MainWindow();
    */
    return new DiagWindow();
}

int main(int argc, char *argv[]) {
#ifdef Q_OS_LINUX
    setenv("XDG_SESSION_TYPE", "x11", 1);
#endif
    QApplication a(argc, argv);
    QTranslator translator;
    const QStringList uiLanguages = QLocale::system().uiLanguages();
    for (const QString &locale : uiLanguages) {
        const QString baseName = "ufprog_" + QLocale(locale).name();
        if (translator.load(":/i18n/" + baseName)) {
            a.installTranslator(&translator);
            break;
        }
    }
    QScopedPointer<QMainWindow> w(createWindow(argc, argv));
    w->show();
    return a.exec();
}

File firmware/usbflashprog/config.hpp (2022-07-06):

// ---------------------------------------------------------------------------
// USB EPROM/Flash Programmer
//
// Copyright (2022) Robson Martins
//
// This work is licensed under a Creative Commons Attribution-NonCommercial-
// ShareAlike 4.0 International License.
// ---------------------------------------------------------------------------
/** 
 * @ingroup Firmware
 * @file config.hpp
 * @brief Configuration of UsbFlashProg.
 * 
 * @author Robson Martins (https://www.robsonmartins.com)
 */
// ---------------------------------------------------------------------------

#ifndef CONFIG_HPP_
#define CONFIG_HPP_

#include "pico/stdlib.h"
#include "hal/adc.hpp"
#include "hal/pwm.hpp"
#include "modules/vgenerator.hpp"

// ---------------------------------------------------------------------------

/** @brief VDD/PWM : Assigned PWM GPIO pin. */
constexpr uint     kVddPwmPin  = 20;
/** @brief VDD/PWM : PWM Frequency, in Hertz. */
constexpr uint32_t kVddPwmFreq = Pwm::kPwmDefaultFreq;

/** @brief VDD/PWM : PWM Min Duty Cycle, in Percent. */
constexpr float    kVddPwmMinDuty
    = VddConfig::kPwmMinDutyCycleDefault;

/** @brief VDD/PWM : PWM Max Duty Cycle, in Percent. */
constexpr float    kVddPwmMaxDuty
    = VddConfig::kPwmMaxDutyCycleDefault;

/** @brief VDD/PWM : PWM Slow Step Duty Cycle, in Percent. */
constexpr float    kVddPwmSlowStepDuty
    = VddConfig::kPwmSlowStepDutyCycleDefault;

/** @brief VDD/PWM : PWM Fast Step Duty Cycle, in Percent. */
constexpr float    kVddPwmFastStepDuty
    = VddConfig::kPwmFastStepDutyCycleDefault;

/** @brief VDD/PWM : PWM Voltage Tolerance to use Fast Step, in Percent. */
constexpr float    kVddPwmToleranceToFast
    = VddConfig::kPwmToleranceToFastDefault;

/** @brief VDD/ADC : Assigned ADC channel. */
constexpr uint     kVddAdcChannel    = 0;
/** @brief VDD/ADC : ADC Reference Voltage, in Volts. */
constexpr float    kVddAdcVRef       = Adc::kAdcDefaultVRef;
/** @brief VDD/VC : Voltage Converter Feedback R1 resistor, in Ohms. */
constexpr float    kVddFbR1          = 470.0f;
/** @brief VDD/VC : Voltage Converter Feedback R2 resistor, in Ohms. */
constexpr float    kVddFbR2          = 330.0f;
/** @brief VDD/VC : Voltage Converter Feedback Divisor, from 0.0 to 1.0. */
constexpr float    kVddDivider        = (kVddFbR1 + kVddFbR2) / kVddFbR2;
/** @brief VDD/VC : Output Voltage Tolerance, in percent. */
constexpr float    kVddVoutTolerance = VddConfig::kDc2DcVoutToleranceDefault;

/** @brief VDD/CTRL : Assigned Voltage Control GPIO pin. */
constexpr uint     kVddCtrlPin     = 22;
/** @brief VDD/CTRL : Assigned VDD on VPP GPIO pin. */
constexpr uint     kVddOnVppPin   = 17;

// ---------------------------------------------------------------------------

/** @brief VPP/PWM : Assigned PWM GPIO pin. */
constexpr uint     kVppPwmPin  = 21;
/** @brief VPP/PWM : PWM Frequency, in Hertz. */
constexpr uint32_t kVppPwmFreq = Pwm::kPwmDefaultFreq;

/** @brief VPP/PWM : PWM Min Duty Cycle, in Percent. */
constexpr float    kVppPwmMinDuty
    = VddConfig::kPwmMinDutyCycleDefault;

/** @brief VPP/PWM : PWM Max Duty Cycle, in Percent. */
constexpr float    kVppPwmMaxDuty
    = VddConfig::kPwmMaxDutyCycleDefault;

/** @brief VPP/PWM : PWM Slow Step Duty Cycle, in Percent. */
constexpr float    kVppPwmSlowStepDuty
    = VddConfig::kPwmSlowStepDutyCycleDefault;

/** @brief VPP/PWM : PWM Fast Step Duty Cycle, in Percent. */
constexpr float    kVppPwmFastStepDuty
    = VddConfig::kPwmFastStepDutyCycleDefault;

/** @brief VPP/PWM : PWM Voltage Tolerance to use Fast Step, in Percent. */
constexpr float    kVppPwmToleranceToFast
    = VddConfig::kPwmToleranceToFastDefault;

/** @brief VPP/ADC : Assigned ADC channel. */
constexpr uint     kVppAdcChannel    = 1;
/** @brief VPP/ADC : ADC Reference Voltage, in Volts. */
constexpr float    kVppAdcVRef       = Adc::kAdcDefaultVRef;
/** @brief VPP/VC : Voltage Converter Feedback R1 resistor, in Ohms. */
constexpr float    kVppFbR1          = 3900.0f;
/** @brief VPP/VC : Voltage Converter Feedback R2 resistor, in Ohms. */
constexpr float    kVppFbR2          = 470.0f;
/** @brief VPP/VC : Voltage Converter Feedback Divisor, from 0.0 to 1.0. */
constexpr float    kVppDivider        = (kVppFbR1 + kVppFbR2) / kVppFbR2;
/** @brief VPP/VC : Output Voltage Tolerance, in percent. */
constexpr float    kVppVoutTolerance = VddConfig::kDc2DcVoutToleranceDefault;

/** @brief VPP/CTRL : Assigned Voltage Control GPIO pin. */
constexpr uint     kVppCtrlPin     = 28;
/** @brief VPP/CTRL : Assigned Voltage Control, Shift Register SIN, GPIO pin. */
constexpr uint     kVppVcSinPin   = 12;
/** @brief VPP/CTRL : Assigned Voltage Control, Shift Register CLK, GPIO pin. */
constexpr uint     kVppVcClkPin   = 14;
/** @brief VPP/CTRL : Assigned Voltage Control, Shift Register CLR, GPIO pin. */
constexpr uint     kVppVcClrPin   = 15;
/** @brief VPP/CTRL : Assigned Voltage Control, Shift Register RCK, GPIO pin. */
constexpr uint     kVppVcRckPin   = 13;
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

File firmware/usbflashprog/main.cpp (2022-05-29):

// ---------------------------------------------------------------------------
// USB EPROM/Flash Programmer
//
// Copyright (2022) Robson Martins
//
// This work is licensed under a Creative Commons Attribution-NonCommercial-
// ShareAlike 4.0 International License.
// ---------------------------------------------------------------------------
/** 
 * @defgroup Firmware Firmware Project
 * @brief    Firmware project for USB EPROM/Flash Programmer.
 */
// ---------------------------------------------------------------------------
/** 
 * @ingroup Firmware
 * @file main.cpp
 * @brief Implementation of the Main Routine.
 *  
 * @author Robson Martins (https://www.robsonmartins.com)
 */
// ---------------------------------------------------------------------------

#include "modules/runner.hpp"

// ---------------------------------------------------------------------------

/**
 * @brief Main routine.
 * @return Error code (zero if success).
 */
int main();

/** @brief Runner instance. */
Runner runner;

// ---------------------------------------------------------------------------

int main() {
    runner.init();
    while (true) {
        runner.loop();
    }
    return 0;
}

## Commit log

2022-04-23 Rev.E. CPU changed to Raspberry Pi Pico. Updated diagrams. Removed PT_BR translation.
2022-04-25 Rev.E. Initial hardware design.
    [address_bus.sch, control_signals.sch, cpu.sch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]
2022-04-27 Rev.E. Updated hardware design.
    [address_bus.kicad_sch, address_bus.sch, control_signals.kicad_sch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]
2022-04-28 Rev.E. Updated specifications document and hardware design.
    [address_bus.kicad_sch, control_signals.kicad_sch, data_bus.kicad_sch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]
2022-04-28 Rev.E. Updated readme and hardware BOM.
    [usbflashprog_bom.ods]
2022-04-30 Rev.E. Updated R51 wattage.
    [address_bus.kicad_sch, control_signals.kicad_sch, data_bus.kicad_sch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]
2022-05-04 Rev.E. Updated documentation.
    [usbflashprog_bom.csv, usbflashprog_bom.ods]
2022-05-07 Rev.E. Add ADC class and UT.
2022-05-09 Rev.E. Created PWM Class. Updated documentation.
2022-05-09 Rev.E. Add tests for PWM Class.
2022-05-12 Rev.E. Add DC2DC circuits class and UT. Revised all code and doxygen docs.
2022-05-15 Rev.E. Add Dc2Dc Converter and Voltage Generator classes.
2022-05-16 Rev.E. Add UT for VGenerator and revised Dc2Dc, Pwm and VGenerator classes.
2022-05-16 Rev.E. Add Test Points for VDD/VPP/GND.
    [address_bus.kicad_sch, control_signals.kicad_sch, serial_bus.kicad_sch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]
2022-05-19 DRAFT. Proposal with Boost Converter to eliminate external power supply.
    [alternative_power.kicad_pcb, alternative_power.kicad_sch]
2022-06-02 Rev.F. Updated schematics
    [address_bus.kicad_sch, control_signals.kicad_sch, cpu.kicad_sch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]
2022-06-02 Rev.F. Ignore backup files from Kicad.
2022-06-03 Rev.F. Ignore backups from Kicad
2022-07-06 Rev.F. Update project
    [address_bus.kicad_sch, control_signals.kicad_sch, cpu.kicad_sch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]

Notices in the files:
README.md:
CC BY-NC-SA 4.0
